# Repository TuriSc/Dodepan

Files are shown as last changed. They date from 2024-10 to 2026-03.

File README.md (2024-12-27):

# Dodepan ­— Digital Synth and Midi controller

This repository contains the firmware and construction files for Dodepan, a portable electronic musical instrument and Midi controller that features a built-in synthesizer, looper, and expressive modulation.

## Overview

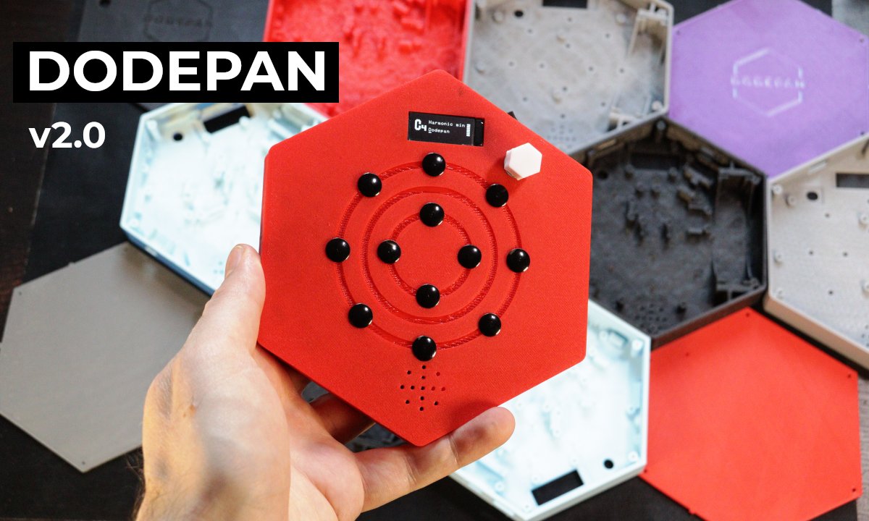
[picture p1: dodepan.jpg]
YouTube Video (https://youtu.be/9P0qgh-Bno8 "Dodepan")

[Video link](https://youtu.be/9P0qgh-Bno8)

Dodepan is played by tapping on its twelve (_dodeka_ in Greek) capacitive metal pads. The instrument features I²S audio output, a rotary encoder for parameter selection, an SSD1306 OLED display, and an MPU-6050 IMU for velocity and pitch bending data.

## What's New

Compared to the original version, this iteration offers several improvements:

* Raspberry Pi Pico 2 as the central unit
* Better audio quality using an I²S DAC and power amplifier
* An SSD1306 OLED display
* A rotary encoder for navigation and parameter selection
* Direct digital synthesis engine
* 9 instrument presets, plus 4 slots for user presets
* Filter cutoff frequency modulation controlled by device tilt
* Sequence looper with diatonic transport selector
* Volume control
* Extended note range
* Automatic storage and retrieval of last used settings
* Fewer components

Dodepan v2 also sports an amplified output with speaker disable. While it can work fine with some headphones, the signal from the audio jack must be attenuated before being connected to sensitive equipment. A resistor between 1.2KΩ and 4.7KΩ is recommended.

## Synth engine and Instrument Parameters

The synth Dodepan is based on is [PRA32-U](https://github.com/risgk/digital-synth-pra32-u) by Ryo Ishigaki.
The instrument parameters section allows you to change the 46 parameters of the synthesizer. Press the encoder button to switch between parameter selection and value editing, and rotate the knob to change parameter or value. Long-press the encoder button to exit this section and store the current instrument to one of the four user presets.

## Looper

The looper section records note on/off events. To enable it, select the looper screen and press the encoder button. An empty square icon indicates no recording. Start playing a melody to automatically start recording. Press the encoder button to stop the recording and start playback. You can play on top of the looper. Press the button again to pause or restart playback. Rotate the encoder knob to perform diatonic transport of the recording.

## IMU Configuration

To make the instrument more expressive, an MPU-6050 IMU (Inertial Measurement Unit) is used to convert the intensity of a tap into velocity data, so that hard taps play louder and soft taps play quieter. The IMU also provides gyroscope data, which Dodepan uses to perform pitch bending, like in a previous toy synth I made, [TS-DET1](https://github.com/TuriSc/TS-DET1).

From the IMU config screen, you can enable or disable pitch bending and filter cutoff modulation when the Dodepan is tilted on the X and Y axes.

## Automatic Save

Dodepan automatically stores the current settings into its memory, with a configurable delay (default 10 seconds) to minimize flash wear. Stored settings are loaded automatically at startup.
The Pico onboard LED will flash briefly when data is being written to its flash memory.

## Built-in Scales

Sixteen built-in scales or modes are available:

* Major (ionian)
* Natural minor (aeolian)
* Harmonic minor
* Dorian
* Lydian
* Mixolydian
* Locrian
* Phrygian
* Phrygian dominant
* Pentatonic major (Diatonic)
* Pentatonic minor
* Pentatonic blues
* Arabian
* Oriental
* Japanese
* Chromatic

You can add up to four custom scales from the scale editing screen, which is accessed by long-pressing the rotary encoder switch while the current scale is selected.

## Secondary menu screens
A number of settings and features are accessible from secondary onboard menu screens.

| Selection  | On press | On long press |
|---|---|---|
| Key | Enter key selection mode | Display about screen |
| Scale | Enter scale selection mode | Enter scale edit screen (long press to exit) |
| Instrument | Enter instrument selection mode | Enter instrument edit screen (long press to exit)  |
| Volume | Enter volume level selection mode | Enter display contrast selection screen |
| Looper | Activate, play/pause | Exit looper screen |
| IMU config | Enter IMU config mode | Exit IMU config screen |

## Installation

To install the firmware, simply flash the provided uf2 file that matches your microcontroller (RP2040 for Raspberry Pi Pico and RP2350 for Raspberry Pi Pico 2). If you want to change any configuration options, you'll need to build the sources and generate your own uf2 file.

## Configuration

All user-configurable options are in the file [config.h](config.h). You can, for example, change pin numbers, MPR121 sensitivity, and timing-related values.

## Compiling

Building the sources requires the Raspberry Pi Pico SDK.

```
git clone https://github.com/TuriSc/Dodepan/
cd Dodepan
git submodule update --init --recursive
mkdir build && cd build
cmake -DPICO_PLATFORM=rp2350 ..
make
```

If you are compiling for RP2040, omit the PICO_PLATFORM directive:
```
cmake ..
make
```
A Raspberry Pi Pico (RP2040) will work but with some limitations. Polyphonic instruments might crackle a bit. To mitigate this, set the Voice Mode parameter to 2 (monophonic).

## Bill of Materials

* Raspberry Pi Pico 2 (RP2350)
* MPR121 (touch sensor)
* GY-521 IMU (MPU-6050 breakout board)
* MAX98357 I²S DAC
* 100KΩ resistor
* 2x 2.2KΩ resistors (external I²C pullup resistors)
* 1000uF electrolytic capacitor (for decoupling, optional. A smaller value is fine)
* Rocker switch (12mm x 8mm hole size)
* 18650 Lithium battery
* One pair of springs for 18650 battery
* TP4056 (charger module)
* SSD1306 0.91" OLED display
* EC11 rotary encoder (12mm height recommended)
* Speaker (4Ω 3W recommended, but 8Ω 2W is fine too)
* 3.5mm audio jack (switched)
* Metal pushpins (to use as touch pads)
* Electrical wire (multi strand 26 AWG)
* M2x5mm screws (10x for the PCB version, 22x for handwired build)
* 3D-printed enclosure, lid, and encoder knob. Handwired build also needs a few small parts

## Schematic

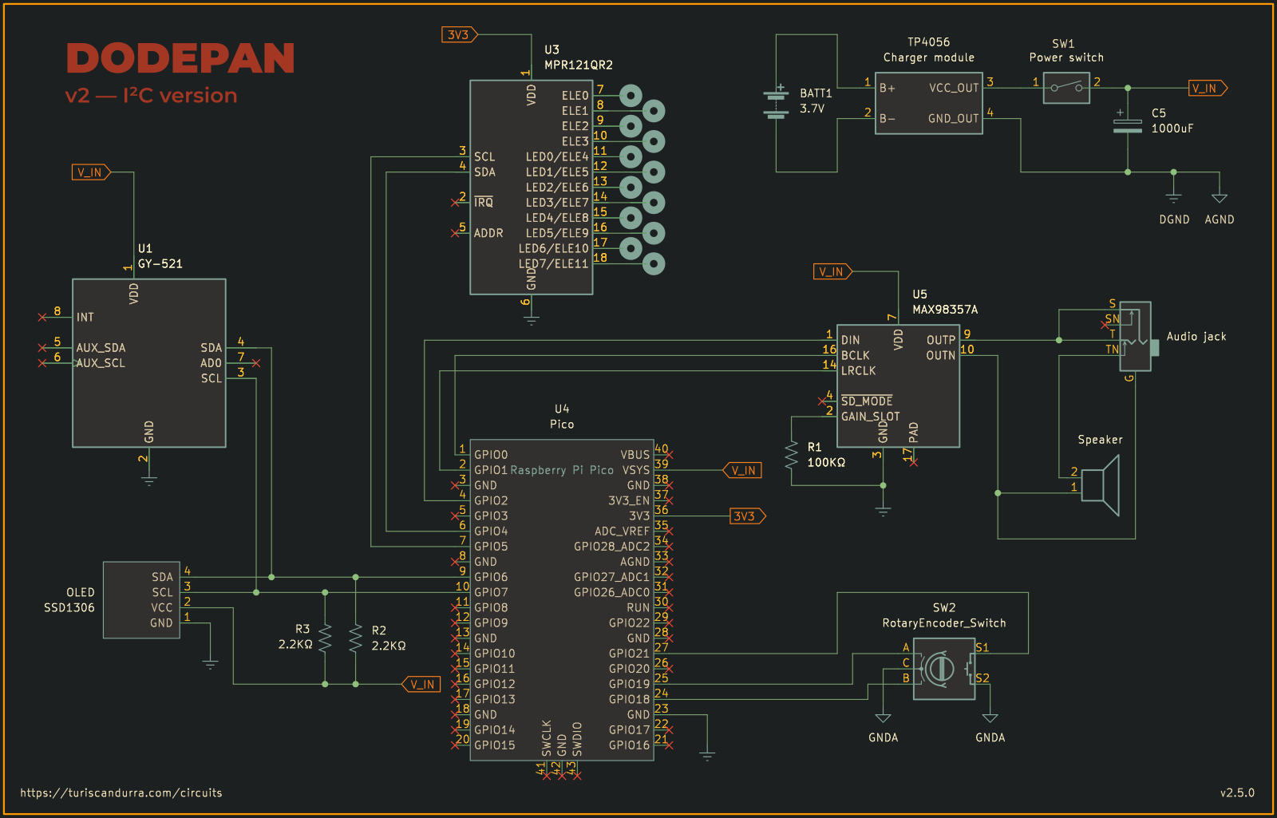
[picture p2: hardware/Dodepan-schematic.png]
Dodepan schematic


[PDF version](hardware/Dodepan-schematic.pdf)

## Step-by-step assembly guide (PCB version)

See [hardware/assembly guide/README.md](hardware/assembly guide/README.md)

## Known bugs

- Playing multiple notes simultaneously while also turning the encoder knob can result in the OLED display glitching.

## More Information

Dodepan is an original project.
Δώδεκα (dodeka) means twelve in Greek. Pan is a reference to the handpan, the instrument that inspired the first version of Dodepan.
The source code for the first version can be found on the version_1 branch at [TuriSc/Dodepan](https://github.com/TuriSc/Dodepan/tree/version_1).  
Similar projects can be found on my blog: [turiscandurra.com/circuits](https://turiscandurra.com/circuits/)

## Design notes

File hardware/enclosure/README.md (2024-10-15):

## Dodepan enclosure 3D models

This folder contains the STL and OpenScad files for the enclosure of Dodepan.

### PCB version

You only need to print:
- Enclosure_PCB
- Lid
- Encoder knob

### Handwired version

You might have to create two or more standoffs to support your speaker.
You also need to print:
- 2x OLED bracket
- 3x Standoff peg (or more if you need them for your speaker)

### Optional print settings

- Fill pattern: Honeycomb
- Fill angle: 30
- Bridging angle: 180

With some filaments the knob might have to be printed at 101% or 99% of its original size due to the filament's tendency to shrink or expand during the printing process.

I printed my lid upside down, to give it a smooth finish and a nice effect on the hexagons. Remember to set the bridging angle to a specified value.

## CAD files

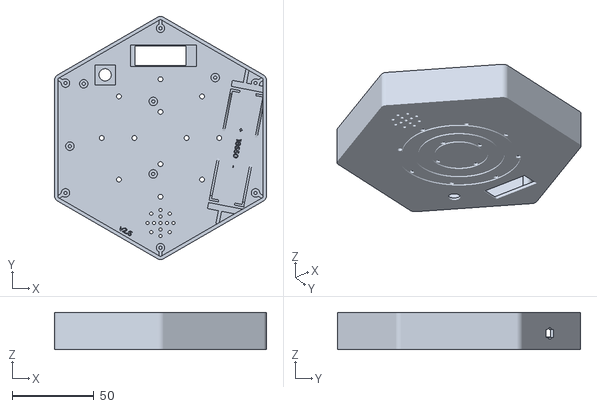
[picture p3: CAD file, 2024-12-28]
hardware/enclosure/Enclosure_PCB.stl
129.9 x 148.8 x 22.9

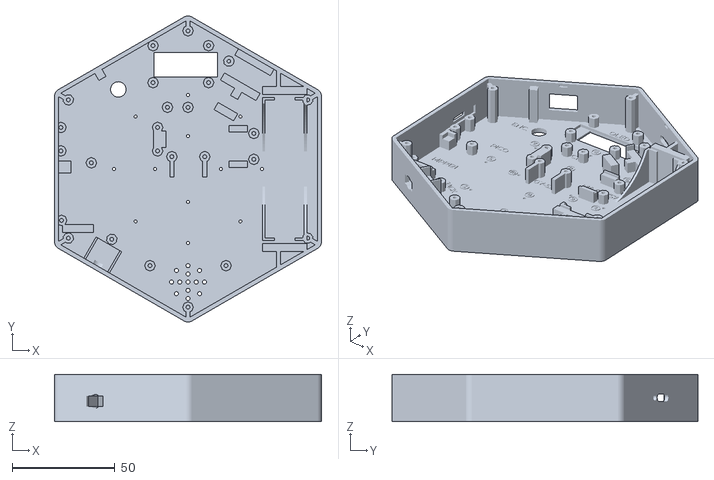
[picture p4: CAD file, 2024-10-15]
hardware/enclosure/Enclosure_handwired.stl
129.9 x 148.8 x 22.9

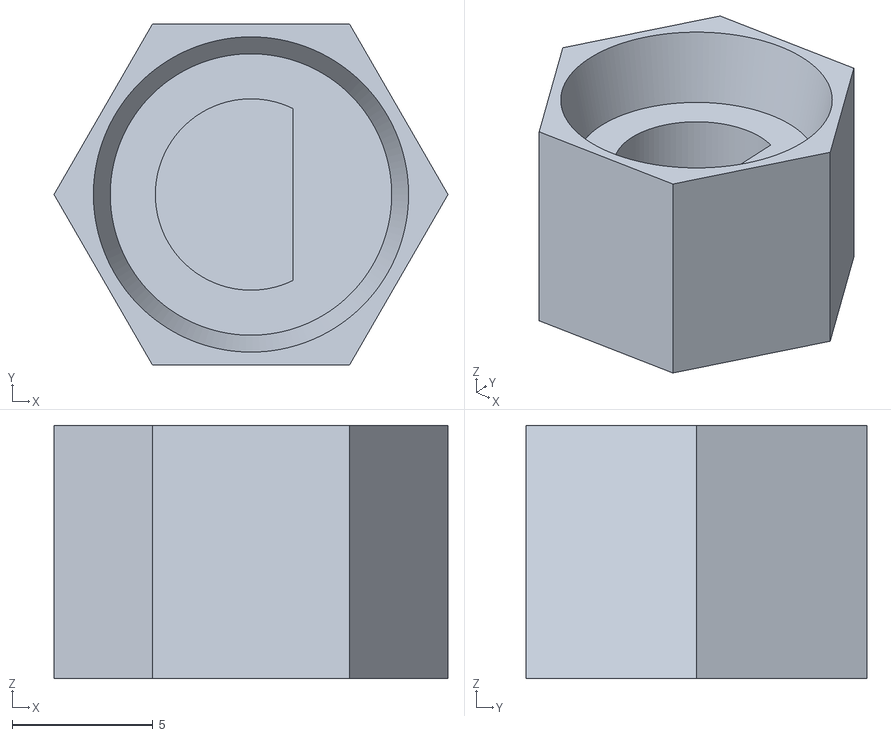
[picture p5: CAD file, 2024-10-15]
hardware/enclosure/Encoder knob.stl
14.0 x 12.1 x 9.00

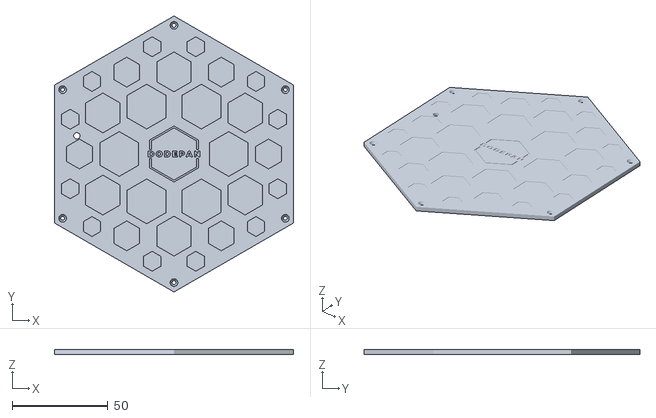
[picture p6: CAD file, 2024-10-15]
hardware/enclosure/Lid.stl
124.9 x 144.2 x 2.40

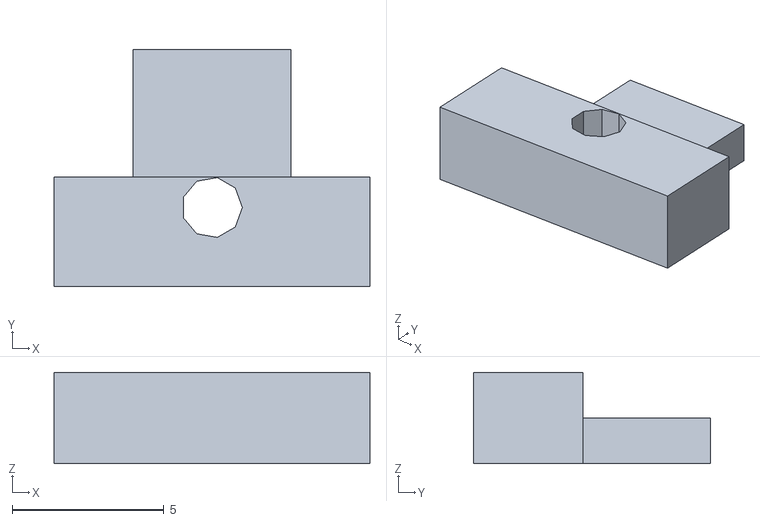
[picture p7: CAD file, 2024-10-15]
hardware/enclosure/Standoff peg.stl
10.4 x 7.80 x 3.00

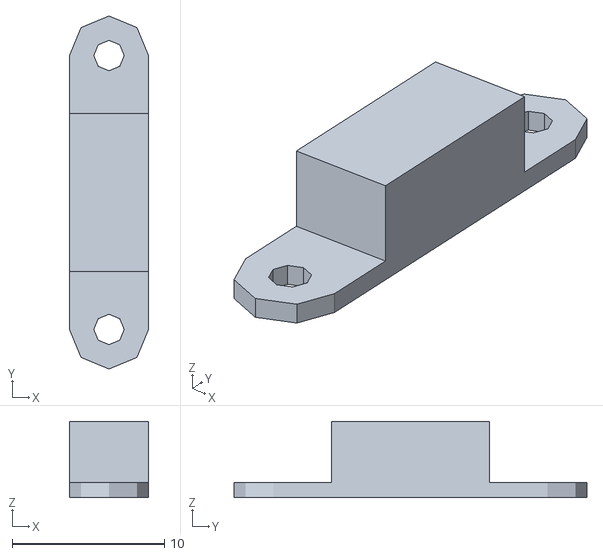
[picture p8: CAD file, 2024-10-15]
hardware/enclosure/OLED bracket.stl
5.20 x 23.2 x 5.00

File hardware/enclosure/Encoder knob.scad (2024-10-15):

// File: Encoder knob.scad
// Description: Knob for an EC11 rotary encoder with a 6mm D-shaft
// Author: Turi Scandurra
// Website: https://www.turiscandurra.com/circuits
// Date: 2024-09-20
// License: MIT License

roof_height = 1;
tolerance = 0.4;
shaft_r = 3 + tolerance;

module knob(height, inset, radius, sides) {
    difference() {
        cylinder(r=radius,h=height,$fn=sides);
        difference() {
            cylinder(r=shaft_r,h=height-roof_height,$fa=0.01,$fs=0.25);
            translate([1.5,-4,0])
                cube([4,8,height-2]);
        }
        cylinder(r1=5.6,r2=5.0,h=inset,$fa=0.01,$fs=0.25);
    }
}

translate([0,0,8])
    rotate([180,0,0])
        knob(9, 3, 7, 6);

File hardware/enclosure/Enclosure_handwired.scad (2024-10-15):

// File: Enclosure_handwired.scad
// Description: Enclosure for Dodepan, handwired (no PCB) version
// Author: Turi Scandurra
// Website: https://www.turiscandurra.com/circuits
// Date: 2024-08-26
// License: MIT License

version_label = "v1.7";

enclosure_r = 75;
inner_h = 20.5;
tolerance = 1.0;

wall_w = 2.4;
floor_h = 2.4;
mount_w = 1.6;
mount_r = enclosure_r - 3.8;

electrode_hole_r = 0.75;
speaker_hole_r = 1.0;
screw_r = 1.0;

electrodes_r_maj = 36;
electrodes_r_min = 16;

snapfit_depth = 2;

pico_mount_height = 9 - floor_h;

six_angles=[0, 60, 120, 180, 240, 300];

// Computed values
enclosure_h = inner_h + floor_h;
enclosure_side_r = enclosure_r * 0.866;

function center(x,y,z) = [x/-2,y/-2,z/-2];

module lid_mount() {
    rotate(-90) translate([-1,-2,0]) cube([2,4,inner_h]);
    translate([-4,0,0]) standoff(inner_h);
}
  
module face_circles() {
    depth = 1;
    rotate_extrude($fn=128) {
        for (radius=[electrodes_r_min, (electrodes_r_min+electrodes_r_maj)/2, electrodes_r_maj]) {
            translate([radius, 0, 0]) square([electrode_hole_r*2,electrode_hole_r*depth], center=true);
        }
    }
}

module rounded_corners() {
    for (a=six_angles) {
            rotate([0,0,a]) translate([enclosure_r-4-0.600, 0, 0]) rotate([0,0,-30]) rotate_extrude(angle=60, $fn=64) {
            translate([4, 0, 0]) square([4,enclosure_h]);
        }
    }
}

module casing() {
    difference() {
        cylinder(r=enclosure_r, h=enclosure_h, $fn=6);
        translate ([0, 0, floor_h]) cylinder(r=(enclosure_r-wall_w), h=enclosure_h, $fn=6);
        rounded_corners();
    }
}

module lid_mounts() {
    for (angle=six_angles) {
        rotate([0,0,angle]){
            translate([mount_r,0,0]) lid_mount();
        }
    }
}

module snapfit_casings() {
    for (angle=[60, 120]) {
        rotate([0,0,30+angle]){
            translate([enclosure_side_r-snapfit_depth,0,inner_h+1]) cube([2,4,1.2], center=true);
        }
    }
}

module electrode_holes() {
        for ( i = [0 : 7] ){
            rotate([0,0,(45*i)])
            translate([0,electrodes_r_maj,0])
            cylinder(h=floor_h, r=electrode_hole_r, $fn=24);
        }
        for ( i = [0 : 3] ){
            rotate([0,0,(90*i)])
            translate([0,electrodes_r_min,0])
            cylinder(h=floor_h, r=electrode_hole_r, $fn=24);
        }
}

module speaker_holes() {
        cylinder(h=floor_h, r=speaker_hole_r, $fn=24);
        for ( i = [0 : 7] ){
            rotate([0,0,(45*i)])
            translate([0,8,0])
            cylinder(h=floor_h, r=speaker_hole_r, $fn=24);
        }
        for ( i = [0 : 3] ){
            rotate([0,0,(90*i)])
            translate([0,4,0])
            cylinder(h=floor_h, r=speaker_hole_r, $fn=24);
        }
}

module battery_holder() {
    max_object_height=inner_h-floor_h;
    translate([0,-13,0]) rotate(180) label("+    18650    -");
    difference() {
        union() {
            // Main shape
            translate(center(69+11,18+3.6,0)) cube([69+11,18+3.6,max_object_height]);
            // Supports
            translate(center(96,-4,0)) cube([96,2,max_object_height]);
        }
        // Battery socket
        translate(center(65+2,18+1,0)) cube([65+2,18+1,max_object_height]);
        // Positive terminal socket
        translate([35.5,0,0]) translate(center(1.5,24,0)) cube([1.5,24,max_object_height]);
        // Negative terminal socket
        translate([-35.5,0,0]) translate(center(1.5,24,0)) cube([1.5,24,max_object_height]);
        // Terminal openings
        translate(center(70,10,0)) cube([70,10,max_object_height]);
        // Circular cut
        translate([0,20,35]) rotate([90,0,0]) cylinder(h=55, r=36, $fn=128);
    }
}

module standoff(height) {
    difference() {
        cylinder(r = mount_w + screw_r, h = height,$fn=8);
        cylinder(r = screw_r, h = height,$fn=8);
    }
}
module label(string) {
    linear_extrude(height = 0.5)
    text(string, font = "Montserrat", halign="center", valign="center", size=3);
}

module GY_521() {
    translate([0,3,0]) label("GY-521");
    translate([8.15,9,0]) standoff(8);
    translate([7.15,-1,0]) cube([2,8,8]);
    translate([-7.85,9,0]) standoff(8);
    translate([-8.85,-1,0]) cube([2,8,8]);
}

module pico() {
    label("PICO");
    translate([-22.8,0,0]) {  // Top holes
        translate([0,-5.7,0]) standoff(pico_mount_height);
        translate([0,5.7,0]) standoff(pico_mount_height);
    }
    translate([24.2,0,0]) { // Bottom holes
        translate([0,-5.7,0]) standoff(pico_mount_height);
        translate([0,5.7,0]) standoff(pico_mount_height);
        translate([-2,-4,0]) cube([6,8,pico_mount_height]);
        translate([2,-4,0]) cube([2,8,pico_mount_height+1]);
    }   
}

module TP4056() {
    translate([0,-13,0]) label("TP4056");
    difference() {
        translate([-10,-8,0]) cube([20,4,8]);
        translate([-10,-8,5.4]) cube([19,4,8]);
    }
    difference() {
        translate([-10,-22,0]) cube([20,4,8]);
        translate([-9,-22,5.4]) cube([18,4,8]);
    }
    translate([-5.5,-36,0]) cube([11,4,8]);
    translate([-2,-26,0]) cube([4,4,5.4]);
    translate([-11,-12,0]) difference() {
        cylinder(r = mount_w + screw_r, h = 5.4);
        cylinder(r = screw_r, h = 5.4);
    }
}

module TP4056_holes() {
    rotate([90,0,0])
    linear_extrude(5) {
        hull() {
            translate([-3.6,0,0]) circle(1.8, $fn=64);
            translate([3.6,0,0]) circle(1.8, $fn=64);
        }
        translate([7.6,0,0]) circle(1.4, $fn=64); // LED hole
    }
}

module electrode_label(string) {
    linear_extrude(height = 0.5){
        text(string, font = "Montserrat", halign="center",valign="center",size=2.2);
        difference() {
            circle(2.4, $fn=16);
            circle(2, $fn=16);
        }
    }
}

module electrode_labels() {
    translate([0, -12]) electrode_label("0");
    translate([0, -32]) electrode_label("1");
    translate([28, -23]) electrode_label("2");
    translate([-29.5, -25]) electrode_label("3");
    translate([33, -2.5]) electrode_label("4");
    translate([-36, 4]) electrode_label("5");
    translate([28.3, 28.3]) electrode_label("6");
    translate([-28.3, 28.3]) electrode_label("7");
    translate([0, 40]) electrode_label("8");
    translate([19, -2.5]) electrode_label("9");
    translate([-19.5, 0]) electrode_label("10");
    translate([0, 20]) electrode_label("11");
}

module MAX98357() {
    amp_mount_h = 5;
    label("MAX98357");
    rotate([0,0,-90]) {
        translate([-6.3,7]) standoff(amp_mount_h);
        translate([-9.2,-5,0]) cube([2.2,9,amp_mount_h]);
        translate([-10.2,-5,0]) cube([1,9,amp_mount_h+1]);
        mirror([180,0,0]){
            translate([-6.3,7]) standoff(amp_mount_h);
            translate([-9.2,-5,0]) cube([2.2,9,amp_mount_h]);
            translate([-10.2,-5,0]) cube([1,9,amp_mount_h+1]);
        }
    }
}
    
module audio_socket() {
    audio_socket_mount_h = 5;
    translate([7,8,0]) label("JACK");
    translate([7,2.8,0]) standoff(audio_socket_mount_h);
    difference() {
        translate([-.2,-12,0]) cube([14.4,12,10]);
        translate([.8,-13,5]) cube([12.4,14.4,5]);
        translate([7.2,-10,7.5]) rotate([90,0,0]) cylinder(r=3.4,h=5,$fn=64);
    }
}

module audio_socket_hole() {
    translate([2.4,-20,5]) cube([9.4,12.4,5]);
    translate([7.2,-10,7.5]) rotate([90,0,0]) cylinder(r=3.4,h=5,$fn=64);
}

module speaker_mount() {
    speaker_mount_h=8;
    translate([0,-4]) label("SPEAKER");
    translate([-18.5,-9]) standoff(speaker_mount_h);
    translate([18.5,-9]) standoff(speaker_mount_h);
}

module OLED() {
    translate([-1.5,8]) label("OLED");
    oled_mount_top_h=5;
    translate([9,-9]) standoff(oled_mount_top_h);
    translate([9,9]) standoff(oled_mount_top_h);
    translate([-18,-9]) standoff(oled_mount_top_h);
    translate([-18,9]) standoff(oled_mount_top_h);
}

module MPR121() {
    rotate([0, 0, -90]) label("MPR121");
    mpr121_mount_h=5;
    translate([-16,-5,0]) cube([2,15,mpr121_mount_h]);
    translate([-18,-5,0]) cube([2,15,mpr121_mount_h+2]);
    difference() {
        translate([11,6,0]) cube([6,6,mpr121_mount_h+2]);
        translate([-15,-10,mpr121_mount_h]) cube([30,20,3]);
    }
    translate([-12,10.5]) standoff(mpr121_mount_h);
    translate([16,-4]) standoff(mpr121_mount_h);
}

module capacitor() {
    label("C1");
    cap_mount_h = 5;
    translate([-5,0,0]) standoff(cap_mount_h);
    translate([5,0,0]) standoff(cap_mount_h);
}
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

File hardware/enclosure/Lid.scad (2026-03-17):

// File: Enclosure_lid.scad
// Description: Enclosure lid for Dodepan
// Author: Turi Scandurra
// Website: https://www.turiscandurra.com/circuits
// Date: 2024-09-20
// License: MIT License

enclosure_r = 75;
tolerance = 1.0;
wall_w = 2.4;
height = 2.4;
mount_r = enclosure_r - 3.8;
enclosure_side_r = enclosure_r * 0.866;
inset_h = 0.6;
logo_w = 45;
logo_h = 48.8;
logo_inset = 0.6;
six_angles = [0, 60, 120, 180, 240, 300];

module graphics() {
    for (angle=six_angles) {
        // Ring 1
        rotate([0,0,angle])
                translate([22, 0, 0]) rotate([0,0,30]) cylinder(h=1, r=9, center=true, $fn=6);
        
        // Ring 2
        rotate([0,0,30+angle])
                translate([33, 0, 0]) cylinder(h=1, r=8, center=true, $fn=6);

        // Ring 3
        rotate([0,0,angle])
                translate([38, 0, 0]) rotate([0,0,30]) cylinder(h=1, r=6, center=true, $fn=6);
        
        // Ring 4 A
        rotate([0,0,18.5+angle])
                translate([44, 0, 0]) rotate([0,0,-48.5])cylinder(h=1, r=4, center=true, $fn=6);
            
        // Ring 4 B
        rotate([0,0,41.5+angle])
                translate([44, 0, 0]) rotate([0,0,-11.5])cylinder(h=1, r=4, center=true, $fn=6);
    }
}

module logo() {
    difference(){
        union(){
            polygon(points=[
                [-0.0, 26.89677],
                [2.36022, 26.89677],
                [3.13389, 26.82012],
                [3.81487, 26.59015],
                [4.37819, 26.21936],
                [4.79889, 25.72022],
                [5.06094, 25.10877],
                [5.14829, 24.40106],
                [5.06094, 23.69335],
                [4.79889, 23.0819],
                [4.37819, 22.58276],
                [3.81487, 22.21197],
                [3.13389, 21.982],
                [2.36022, 21.90535],
                [-0.0, 21.90535]
            ]);
            polygon(points=[
                [9.59164, 21.80552],
                [8.83936, 21.88931],
                [8.16552, 22.14066],
                [7.60398, 22.53997],
                [7.17437, 23.06764],
                [6.90697, 23.69691],
                [6.81784, 24.40106],
                [6.90697, 25.10521],
                [7.17437, 25.73448],
                [7.60398, 26.26215],
                [8.16552, 26.66146],
                [8.83936, 26.91281],
                [9.59164, 26.9966],
                [10.34214, 26.91281],
                [11.01063, 26.66146],
                [11.57573, 26.26215],
                [12.00178, 25.73448],
                [12.27453, 25.10521],
                [12.36544, 24.40106],
                [12.27453, 23.69691],
                [12.00178, 23.06764],
                [11.57573, 22.53997],
                [11.01063, 22.14066],
                [10.34214, 21.88931]
            ]);
            polygon(points=[
                [14.2917, 26.89677],
                [16.65192, 26.89677],
                [17.42559, 26.82012],
                [18.10657, 26.59015],
                [18.66988, 26.21936],
                [19.09059, 25.72022],
                [19.35264, 25.10877],
                [19.43999, 24.40106],
                [19.35264, 23.69335],
                [19.09059, 23.0819],
                [18.66988, 22.58276],
                [18.10657, 22.21197],
                [17.42559, 21.982],
                [16.65192, 21.90535],
                [14.2917, 21.90535]
            ]);
            polygon(points=[
                [25.37363, 22.99633],
                [25.37363, 21.90535],
                [21.36624, 21.90535],
                [21.36624, 26.89677],
                [25.28093, 26.89677],
                [25.28093, 25.80579],
                [22.76384, 25.80579],
                [22.76384, 24.96438],
                [24.98145, 24.96438],
                [24.98145, 23.90905],
                [22.76384, 23.90905],
                [22.76384, 22.99633]
            ]);
            polygon(points=[
                [29.62446, 26.89677],
                [30.80101, 26.66859],
                [31.57112, 26.02684],
                [31.77434, 25.57583],
                [31.84208, 25.04995],
                [31.77434, 24.52407],
                [31.57112, 24.07306],
                [30.80101, 23.4313],
                [29.62446, 23.21025],
                [28.75453, 23.21025],
                [28.75453, 21.90535],
                [27.34267, 21.90535],
                [27.34267, 26.89677]
            ]);
            polygon(points=[
                [36.80596, 22.87511],
                [34.6953, 22.87511],
                [34.30312, 21.90535],
                [32.86274, 21.90535],
                [35.06609, 26.89677],
                [36.45656, 26.89677],
                [38.66705, 21.90535],
                [37.19815, 21.90535]
            ]);
            polygon(points=[
                [45.0, 26.89677],
                [45.0, 21.90535],
                [43.83771, 21.90535],
                [41.63436, 24.56507],
                [41.63436, 21.90535],
                [40.25102, 21.90535],
                [40.25102, 26.89677],
                [41.41331, 26.89677],
                [43.61666, 24.23706],
                [43.61666, 26.89677]
            ]);
            // Upper outline
            polygon(points=[
                [22.4999, 48.80217],
                [1.3681, 36.60185],
                [1.3681, 28.42472],
                [2.79564, 28.42472],
                [2.79564, 35.77715],
                [22.4999, 47.15299],
                [42.20416, 35.77715],
                [42.20416, 28.42472],
                [43.63193, 28.42472],
                [43.63193, 36.60185]
            ]);
            // Lower outline
            polygon(points=[
                [1.3681, 20.37743],
                [1.3681, 12.20031],
                [22.4999, -1e-05],
                [43.63193, 12.20031],
                [43.63193, 20.37743],
                [42.20416, 20.37743],
                [42.20416, 13.02478],
                [22.4999, 1.64917],
                [2.79564, 13.02478],
                [2.79564, 20.37743]
            ]);
        };
        union(){
            // D1 island
            polygon(points=[
                [2.30318, 23.03198],
                [2.88076, 23.1229],
                [3.32999, 23.39565],
                [3.62412, 23.82883],
                [3.72217, 24.40106],
                [3.62412, 24.97329],
                [3.32999, 25.40648],
                [2.88076, 25.67922],
                [2.30318, 25.77013],
                [1.41186, 25.77013],
                [1.41186, 23.03198]
            ]);
            // O island
            polygon(points=[
                [9.59164, 22.97494],
                [10.27618, 23.1532],
                [10.76106, 23.65235],
                [10.93932, 24.40106],
                [10.76106, 25.14264],
                [10.27618, 25.64891],
                [9.59164, 25.82718],
                [8.9071, 25.64891],
                [8.42222, 25.14264],
                [8.24396, 24.40106],
                [8.42222, 23.65235],
                [8.9071, 23.1532]
            ]);
            // D2 island
            polygon(points=[
                [16.59488, 23.03198],
                [17.17246, 23.1229],
                [17.62168, 23.39565],
                [17.91582, 23.82883],
                [18.01387, 24.40106],
                [17.91582, 24.97329],
                [17.62168, 25.40648],
                [17.17246, 25.67922],
                [16.59488, 25.77013],
                [15.70355, 25.77013],
                [15.70355, 23.03198]
            ]);
            // P island
            polygon(points=[
                [29.5389, 24.32263],
                [30.19492, 24.50802],
                [30.41597, 25.04995],
                [30.19492, 25.59187],
                [29.5389, 25.7844],
                [28.75454, 25.7844],
                [28.75454, 24.32263]
            ]);
            // A island
            polygon(points=[
                [36.39238, 23.91618],
                [35.75063, 25.51344],
                [35.10888, 23.91618]
            ]);
        }
    }
}

module lid(){
    rotate([0,0,-30])
    difference(){
        // Main shape
        cylinder(r=enclosure_r-wall_w-tolerance/2, h=height, $fn=6);
        // Graphics
        translate([0,0,height]) rotate([0,0,30]) scale([1.3,1.3,inset_h]) graphics();
        // Logo
        rotate([0,0,30]) scale([0.6,0.6,1])
        translate([logo_w/-2, logo_h/-2, height - logo_inset]){
            linear_extrude(height = 1)
                logo();
        }
        // Screw holes
        for (angle=six_angles) {
            rotate([0,0,angle])
                translate([mount_r-4,0,0]) 
                    cylinder(h=height, r1=1, r2=2, $fn=48);
        }
        // BOOTSEL
        rotate([0,0,30]) translate([-50.75, 9.5]) cylinder(h=height, r=1.66, $fn=64);
    }
}

// Render the part
lid();

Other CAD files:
hardware/enclosure/Enclosure_PCB.scad
hardware/enclosure/OLED bracket.scad
hardware/enclosure/Standoff peg.scad

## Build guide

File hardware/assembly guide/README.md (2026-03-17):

# Dodepan step-by-step assembly guide (PCB version)

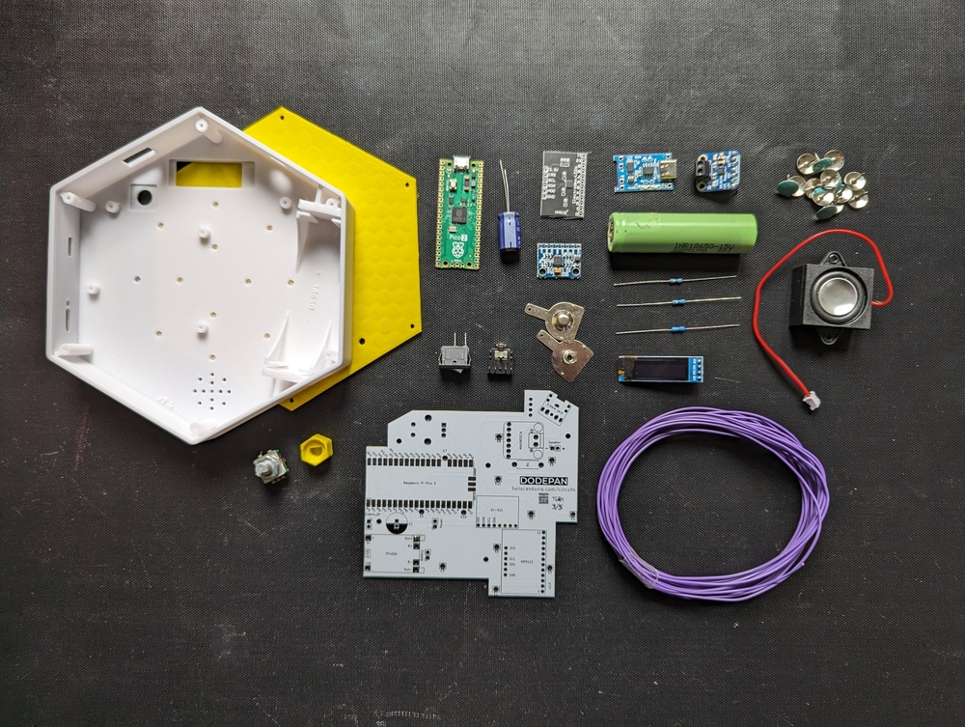
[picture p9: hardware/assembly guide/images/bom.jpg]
bom

1. Solder the MAX98357 module using its headers. Do not solder the speaker terminal to the module. Solder the two speaker output pins to the PCB
2. Solder the speaker terminal to the PCB
3. Solder the R1 resistor for MAX98357
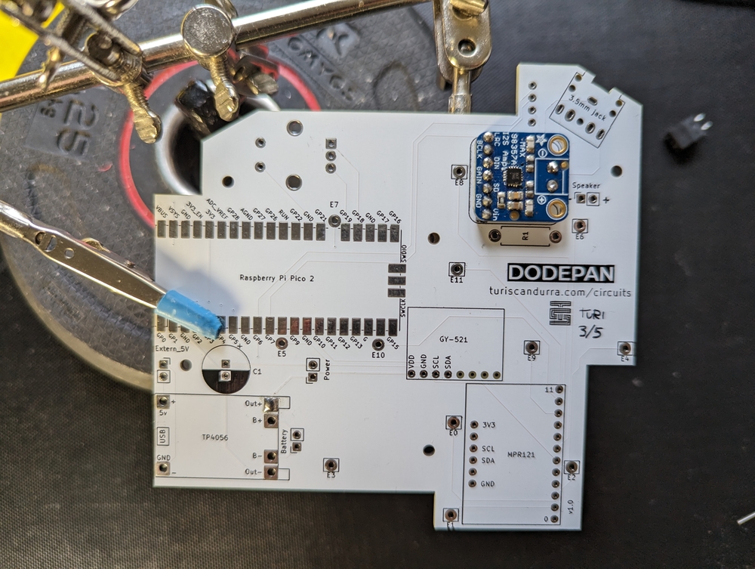
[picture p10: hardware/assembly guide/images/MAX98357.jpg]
MAX98357

1. Solder the GY-521 module to the PCB using its headers. Make sure it's perfectly aligned as it must be located at the center of movement of the enclosure
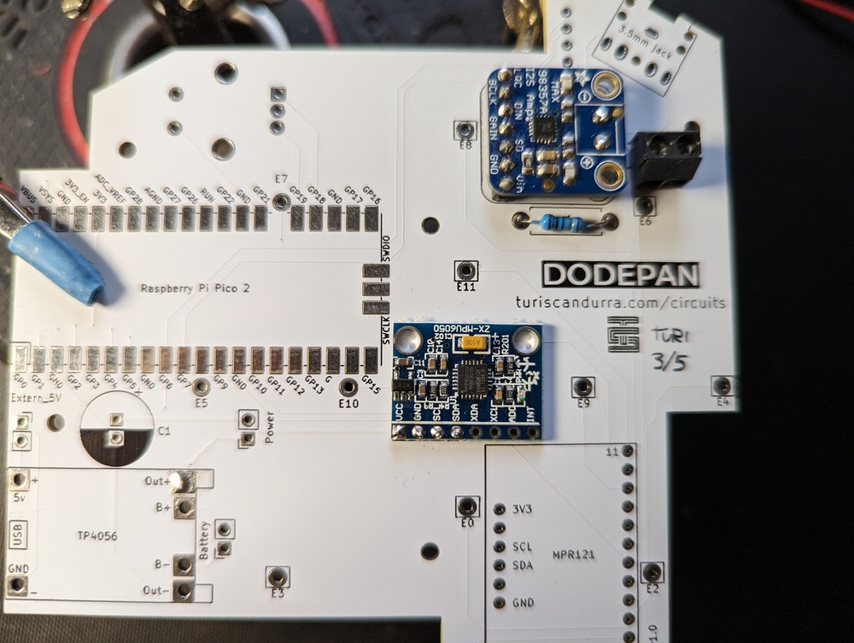
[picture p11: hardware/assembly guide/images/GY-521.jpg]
GY-521

1. Solder the external I²C pullup resistors R2 and R3. Please note that the old version of the PCB used in these pictures does not include the two resistors
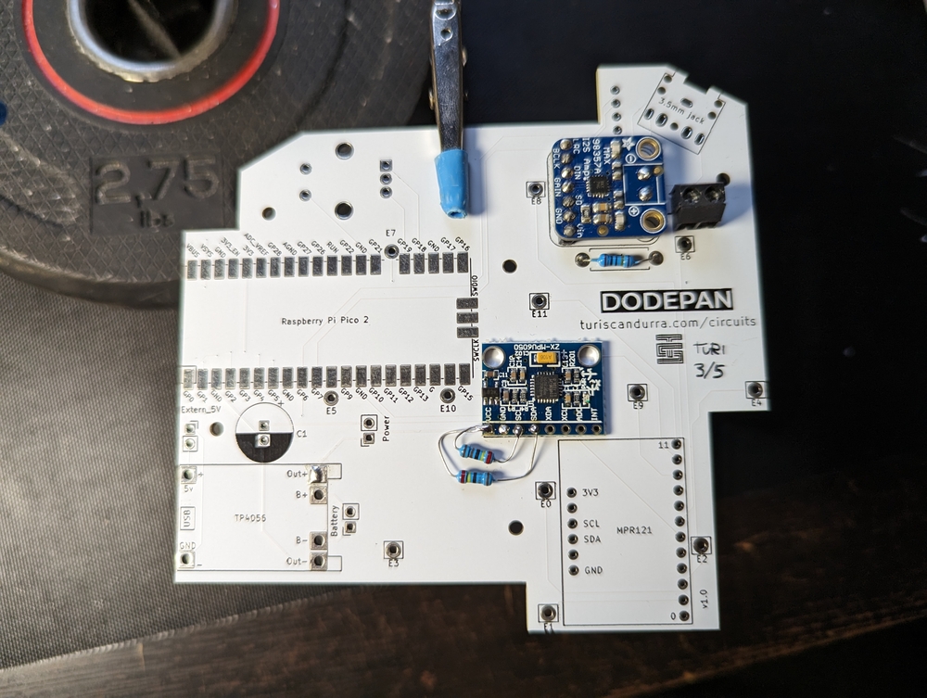
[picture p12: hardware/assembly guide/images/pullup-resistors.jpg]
pullup resistors

1. Solder the MPR121 module to the PCB using its headers
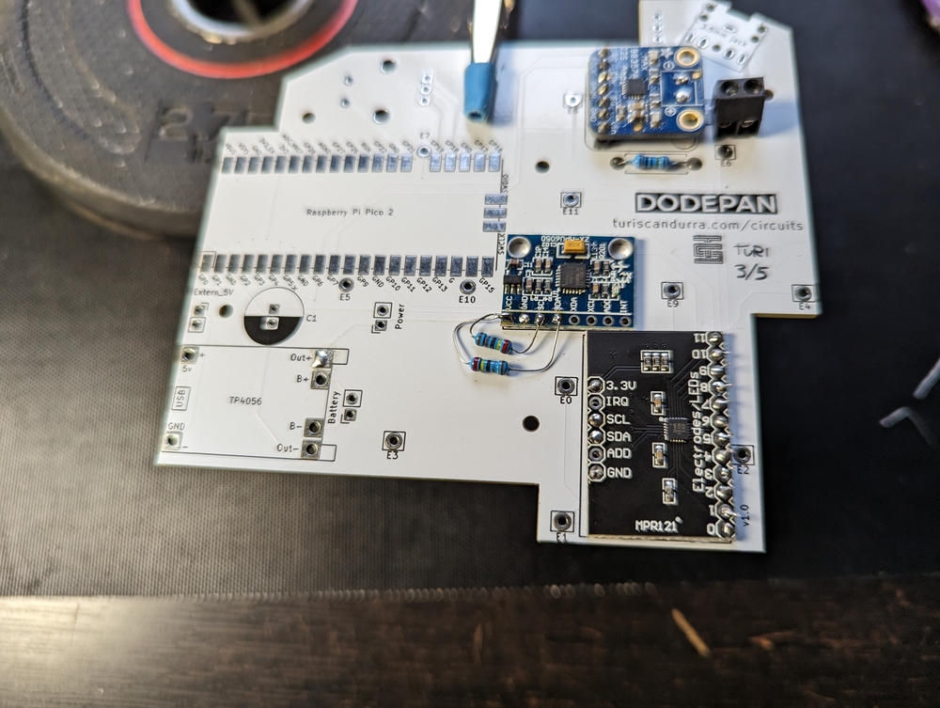
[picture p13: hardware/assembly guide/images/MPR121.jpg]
MPR121

1. Solder the jack socket
2. Solder the power switch wires so that they come out of the back side of the PCB. Do not solder them to the switch yet
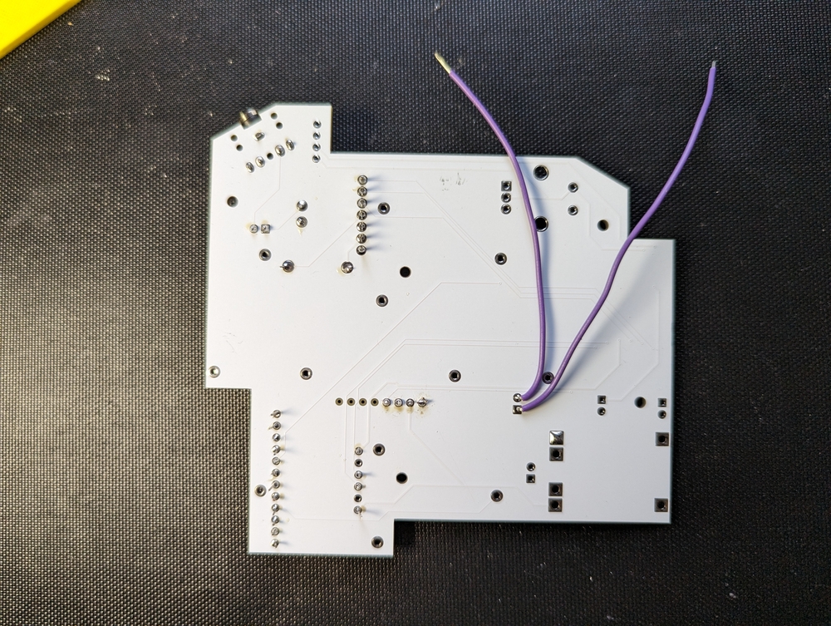
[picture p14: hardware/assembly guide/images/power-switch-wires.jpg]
power switch wires

1. Solder the battery wires so that they come out of the back side of the PCB
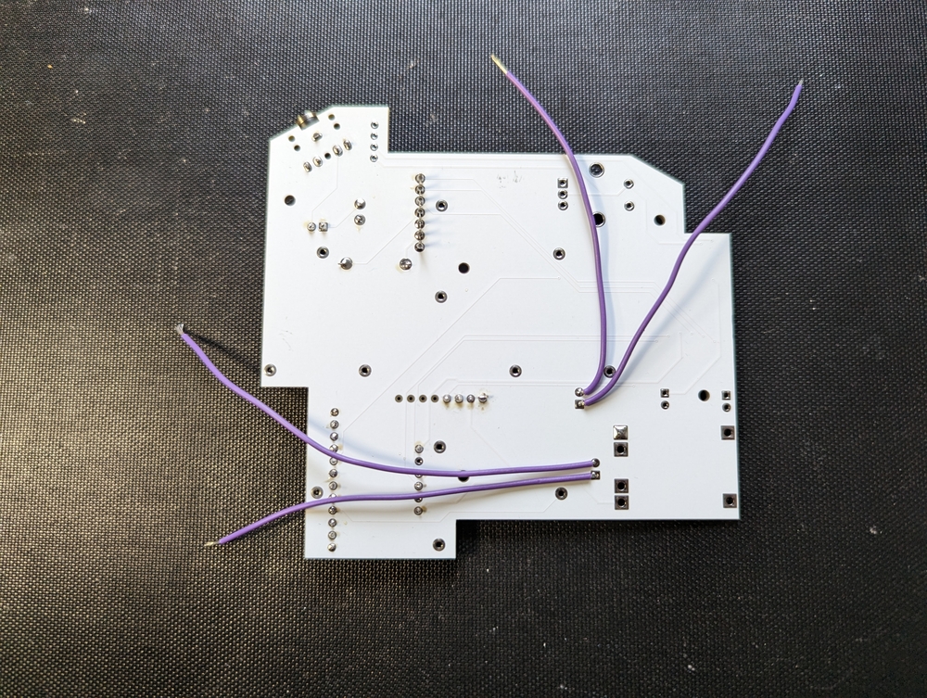
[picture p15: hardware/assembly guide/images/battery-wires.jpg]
battery wires

1. Solder six short solid core wires on the PCB to serve as "headers" for the TP4056 module. Avoid rigid header pins
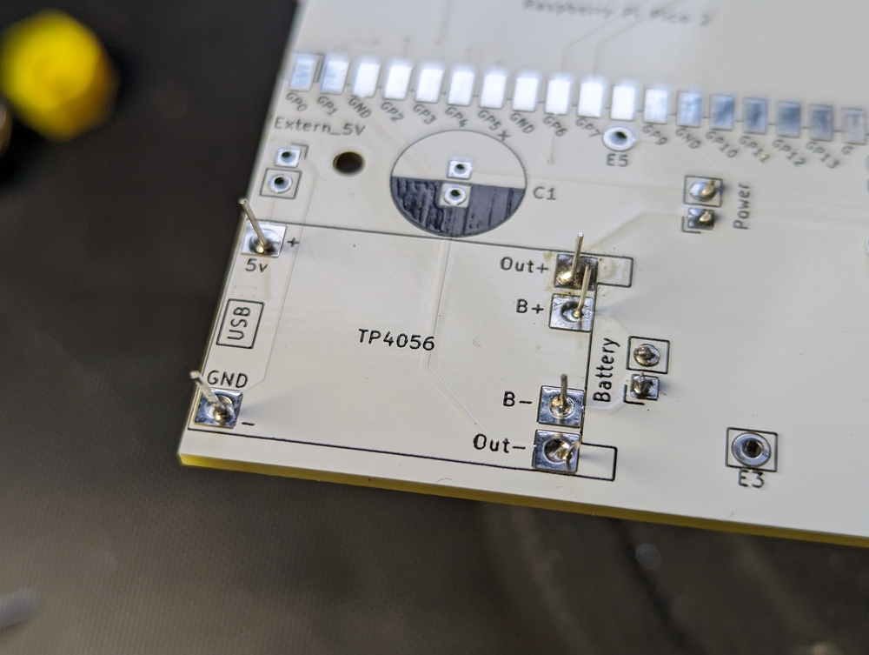
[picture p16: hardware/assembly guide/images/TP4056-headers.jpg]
TP4056 headers

1. Place a thin strip of insulating tape through the four back headers you just soldered (B+, B-, Out+, Out-) and over the four pads underneath. This is needed because there are slightly different TP4056 modules on the market and the pads might not perfectly align. Do not solder the TP4056 yet
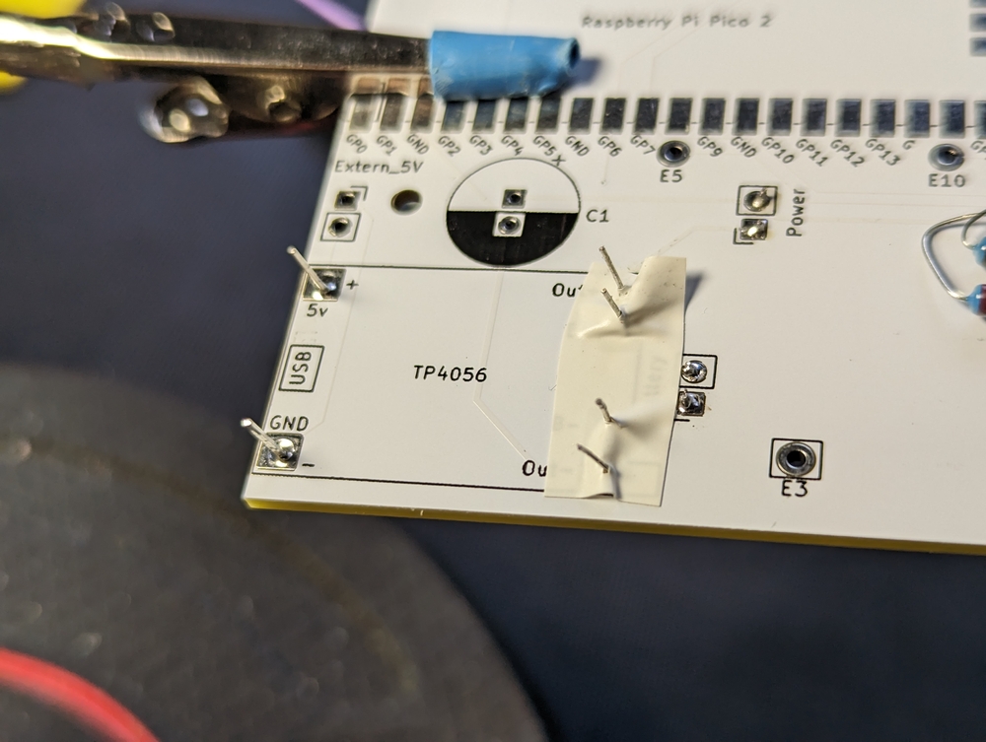
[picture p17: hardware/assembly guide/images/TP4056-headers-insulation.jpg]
TP4056 headers insulation

1. Solder the decoupling capacitor
2. Trim the short side of the OLED headers so they're almost flush with their board. Place the OLED into its slot on the enclosure
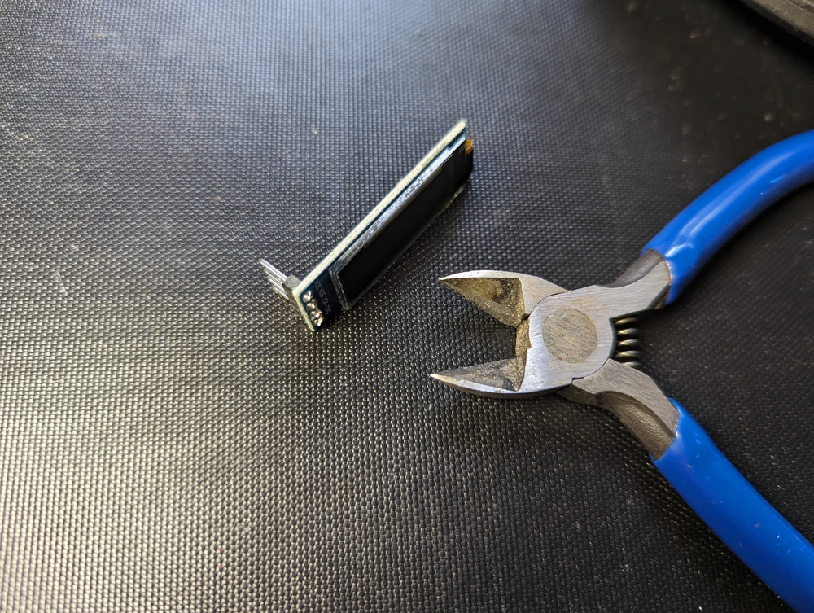
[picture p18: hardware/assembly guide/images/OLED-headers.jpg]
OLED headers

1. Place the rotary encoder on the back side of the PCB without soldering it. Remember to remove the washer and nut
2. Place the speaker inside the enclosure
3. Place the PCB in the enclosure, audio jack first, ensuring the rotary encoder and the OLED are in their correct position and the wires for the battery, the power switch, and the speaker are accessible. Bend the enclosure, not the PCB
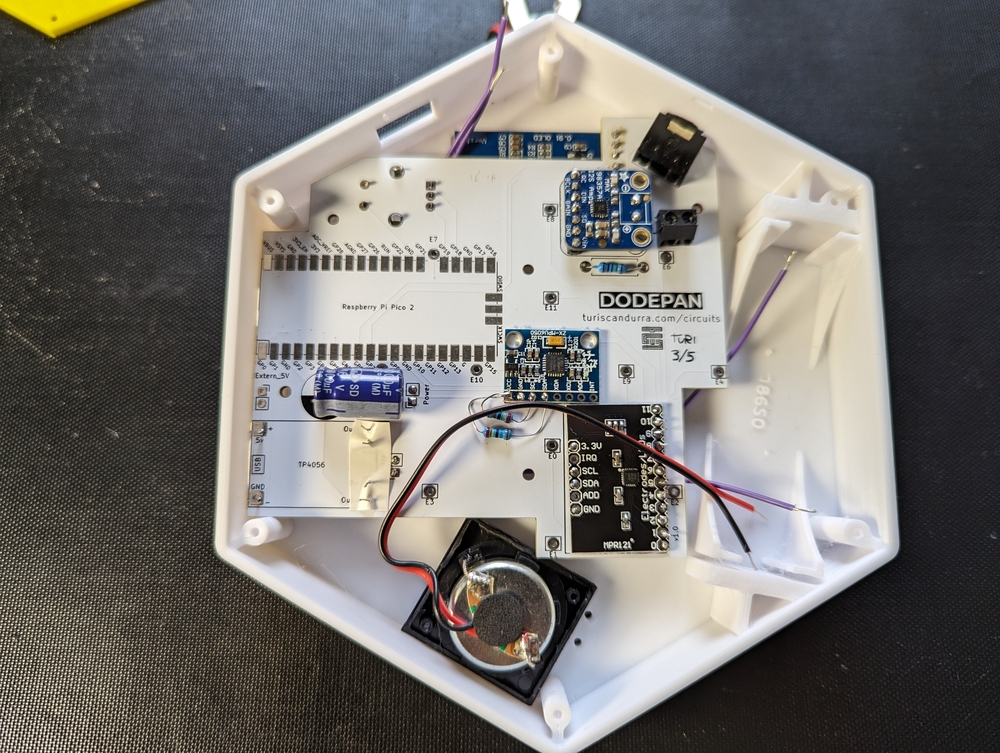
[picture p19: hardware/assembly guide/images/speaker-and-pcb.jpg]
speaker and pcb

1. Solder the OLED display to the PCB
2. Solder the rotary encoder to the PCB
3. Make sure the USB socket of the TP4056 module is fitting into its hole and solder the module to the PCB
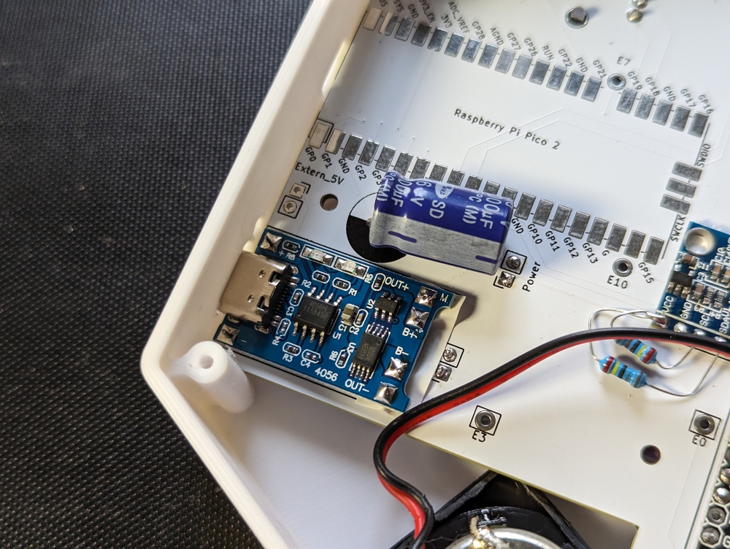
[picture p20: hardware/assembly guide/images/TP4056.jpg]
TP4056

1. Secure the PCB to the enclosure with the M2 screws
2. Place the power switch into its hole and solder its two wires to it
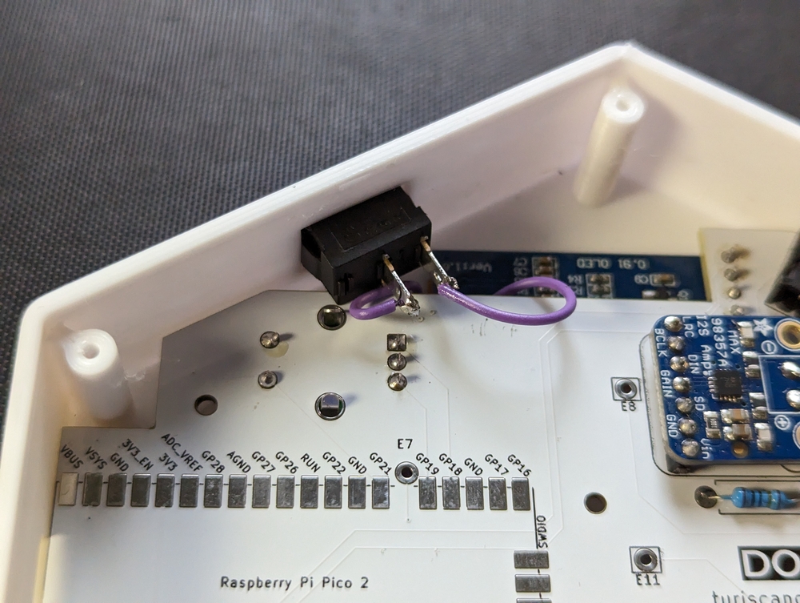
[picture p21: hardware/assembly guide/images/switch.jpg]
switch

1. Place the battery springs into their sockets, bend their tabs outward, and solder them to their wires
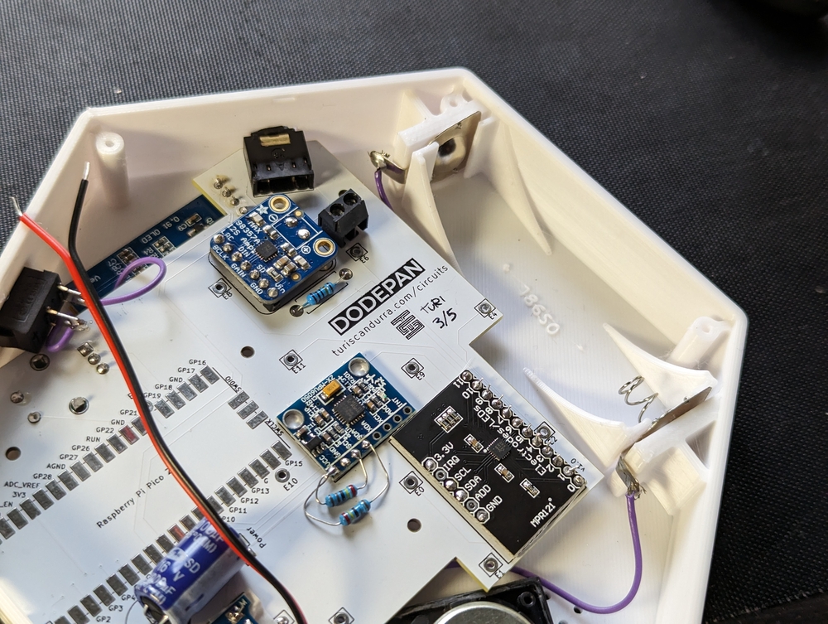
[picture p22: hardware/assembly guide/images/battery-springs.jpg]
battery springs

1. Place the Pico so that the Micro-USB socket goes fully through the enclosure wall. Align it with the pads on the PCB and use some tape to secure it in position as you solder it
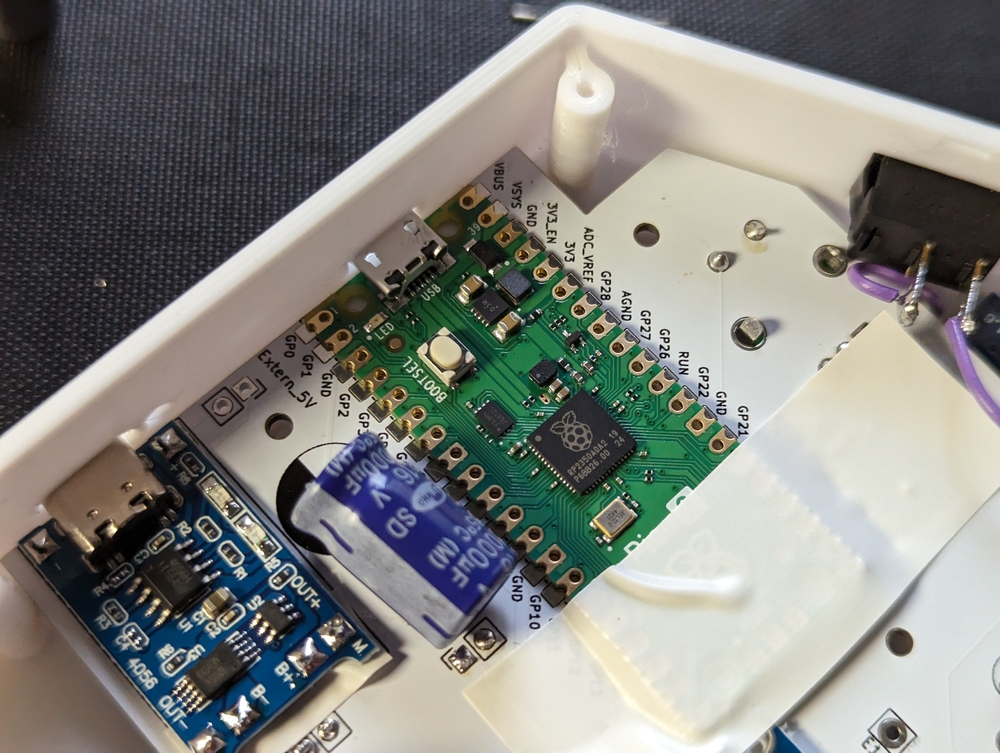
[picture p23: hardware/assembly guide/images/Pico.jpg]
Pico

1. Solder the twelve drawing pins/electrodes. If you painted the pins, be very quick as heat softens the enamel
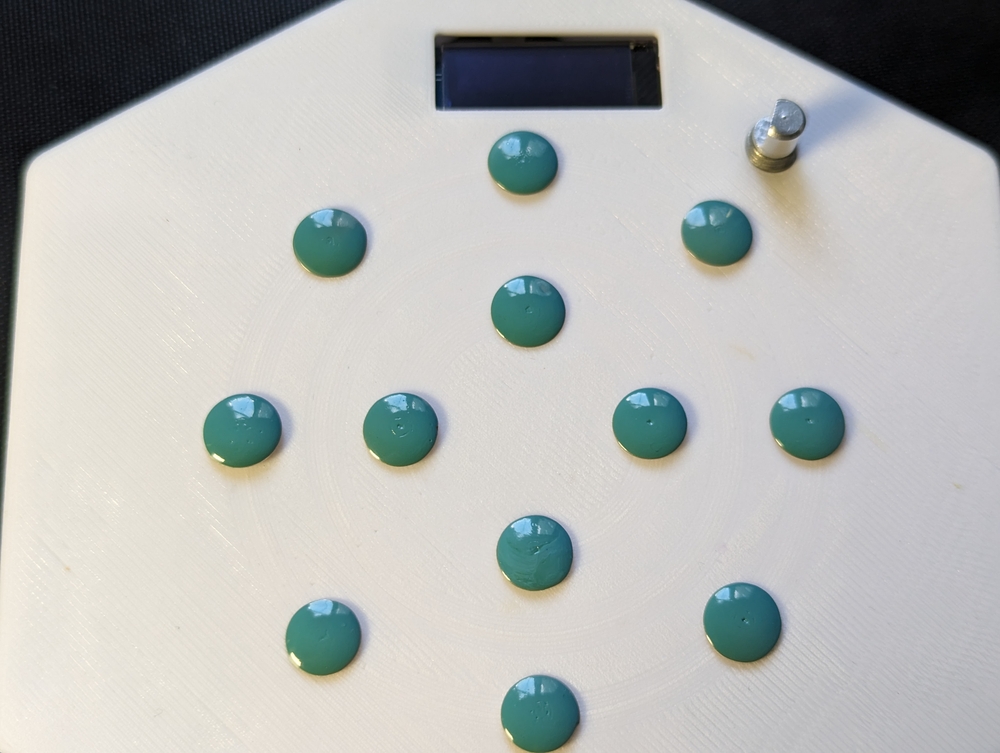
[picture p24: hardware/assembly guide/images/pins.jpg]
pins

1. Lock the speaker wires into the audio output terminal. Use some hot glue to secure the speaker in place 
2. Install the washer, nut, and knob on the rotary encoder
3. Install the battery
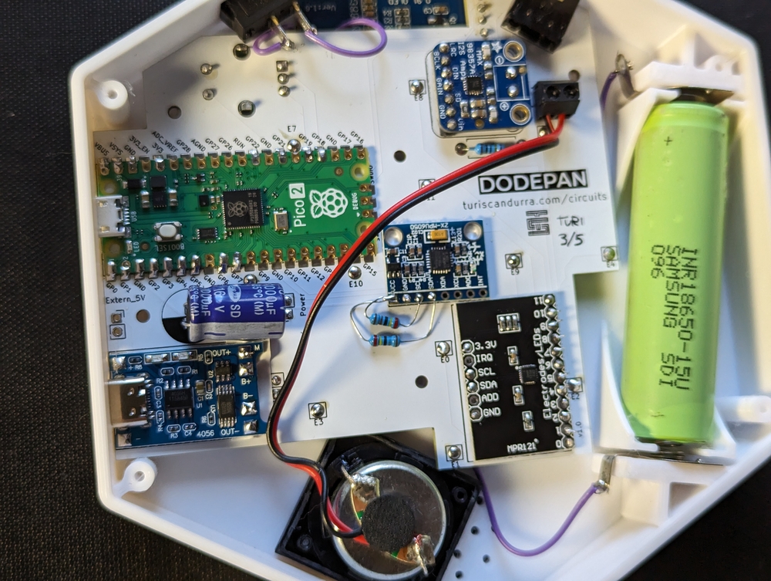
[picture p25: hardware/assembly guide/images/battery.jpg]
battery

1. Flash the firmware on the Pico
2. Install the lid and secure it with the M2 screws

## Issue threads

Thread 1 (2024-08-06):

I2S on Dodepan

grbfst, 2024-08-06:
Hi,
Love the project. How hard/easy is it to implement an I2S sound output on the Dodepan? I see you have already done it for the Picophonica so maybe it's easy (and I don't know how) ?

TuriSc, 2024-08-13:
Hi.
A new version of Dodepan is under development at [TuriSc/Dodepan-I2S](https://github.com/TuriSc/Dodepan-I2S/). It does output sound via I2S, but it's not sample-based as it uses a new audio engine for direct digital synthesis.
This older repository will only cover the PWM version of the instrument.

Closed 2024-08-13.

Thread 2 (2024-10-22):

Crackling

grbfst, 2024-10-22:
Hi, Wonderful project! Just built a Pico (1) and a Pico 2 Dodepan. I noticed quite some crackling, do I need to change something in the I2S settings?

Regards,
Marc

grbfst, 2024-10-22:
It's only when playing a note, I do need the gain because without the resistor the sound is quite soft. I tried no resistor, resistor to ground and to VDD but all give crackling.

TuriSc, 2024-10-23:
Could you please try a smaller speaker (or headphones)? If the crackling stops or is reduced, then it's a power issue, and a decoupling capacitor between the amp's VDD and GND might help.

However, it could be that your CPU is struggling to keep up with audio buffering. Does the problem go away if you disable the two IMU-controlled effects? Disabling them frees up quite some CPU cycles.

A Pico 1 would not be fast enough to flawlessly play multiple notes and process IMU effects at the same time, unless the CPU is overclocked even more, which will affect the overall tuning of the instrument.

grbfst, 2024-10-23:
I will look at the code and see if where I can disable the effects.

Closed 2024-12-01.

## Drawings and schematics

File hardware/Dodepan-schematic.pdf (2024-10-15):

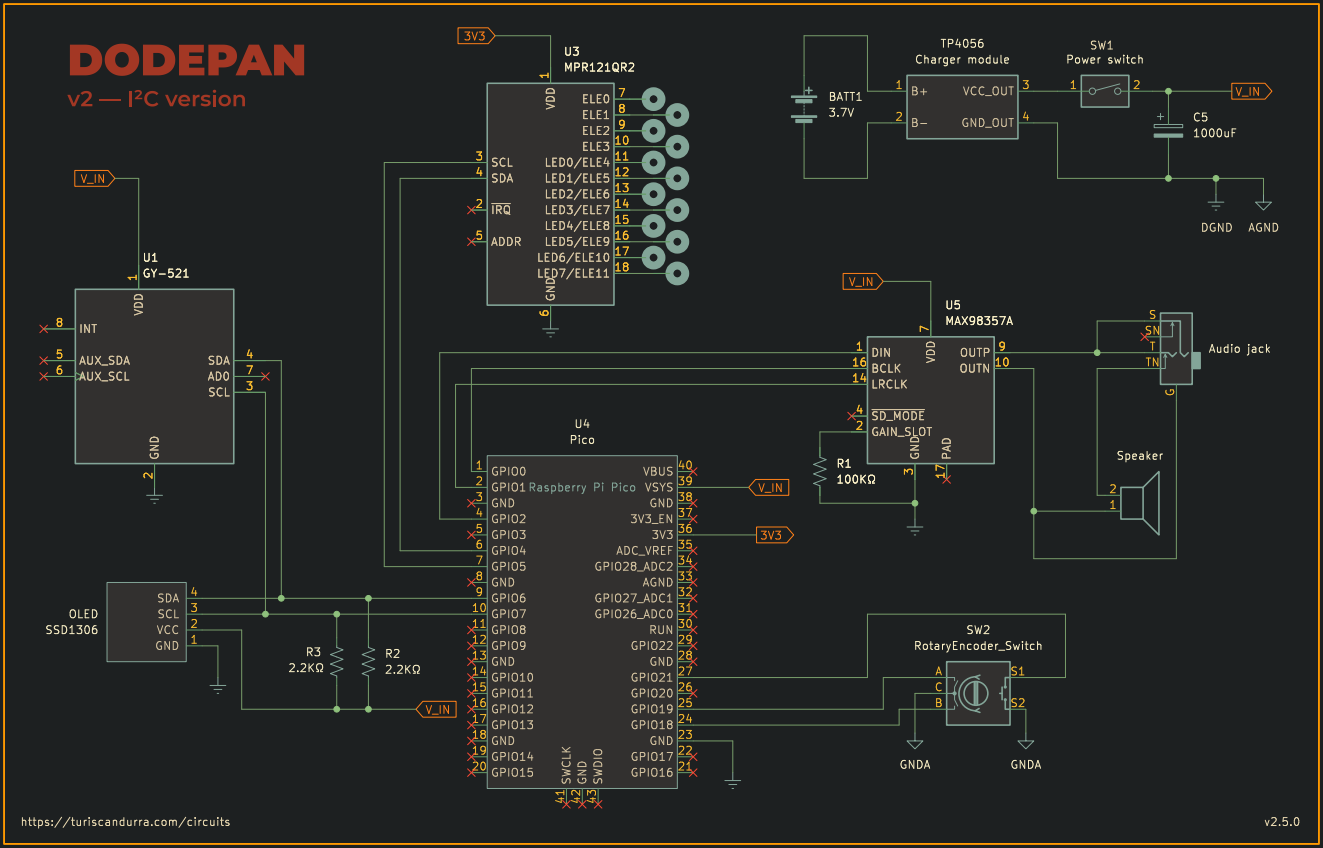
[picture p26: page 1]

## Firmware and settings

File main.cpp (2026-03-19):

/* Dodepan
 * An expressive electronic instrument and Midi controller built on Raspberry Pi Pico".
 * By Turi Scandurra – https://turiscandurra.com/circuits
 */

#include "config.h"         // Most configurable options are here
#include "pico/stdlib.h"
// Arduino types added for compatibility
typedef bool boolean;
typedef uint8_t byte;
#include "hardware/clocks.h"
#include "hardware/gpio.h"
#include "hardware/adc.h"   // Used for low battery detection
#include "hardware/flash.h"
#include "pico/binary_info.h"
#include "pico/multicore.h"
#include "sound_i2s.h"
#include "pra32-u-common.h" // https://github.com/risgk/digital-synth-pra32-u
#include "pra32-u-synth.h"  // PRA32-U version 2.3.1
#include "instrument_preset.h"
#include "encoder.h"        // https://github.com/TuriSc/RP2040-Rotary-Encoder
#include "button.h"         // https://github.com/TuriSc/RP2040-Button
#include "bsp/board_api.h"  // For TinyUSB Midi
#include "tusb.h"           // For TinyUSB Midi
#include "scales.h"
#include "battery-check.h"
#include "imu.h"
#include "touch.h"
#include "looper.h"
#include "display/display.h"
#include "state.h"

/* Globals */

PRA32_U_Synth g_synth;

state_t* state;

Imu_data imu_data;

uint8_t **user_presets;
uint8_t **user_scales;

#if defined (USE_DISPLAY)
ssd1306_t display;
#endif

static alarm_id_t power_on_alarm_id;
static alarm_id_t long_press_alarm_id;
static bool looper_button_pending;
static alarm_id_t flash_write_alarm_id;

void core1_main();

/* User Presets and flash memory */
static inline uint8_t get_argument_from_parameter(uint8_t parameter) {
    uint8_t control_number = dodepan_program_parameters[parameter];
    return g_synth.current_controller_value(control_number);
}

static inline void update_argument_from_parameter(uint8_t parameter) {
    uint8_t control_number = dodepan_program_parameters[parameter];
    uint8_t argument = g_synth.current_controller_value(control_number);
    set_argument(argument);
}

static inline void update_degree() {
    uint8_t step = get_step();
    uint8_t degree = get_degree(step);
    set_extended_scale(step, degree);
    set_scale_unsaved(true); // Used when the user modifies a scale but does not save it,
                             // and the name of the scale must be changed to "Custom"
}

void load_user_preset(uint8_t instrument) {
    uint8_t preset_num = instrument - 9; // Subtracting the 9 default presets
    for (uint32_t i = 0; i < PROGRAM_PARAMS_NUM; i++) {
        g_synth.control_change(dodepan_program_parameters[i], user_presets[preset_num][i]);
    }
}

static inline void sync_control_change() {
    uint8_t parameter = get_parameter();
    uint8_t control_number = dodepan_program_parameters[parameter];
    uint8_t argument = get_argument();
    g_synth.control_change(control_number, argument);
}

void update_instrument() {
    uint8_t instrument = get_instrument();
    switch (instrument) {
        case 0: // Load custom Dodepan preset
            for (uint32_t i = 0; i < PROGRAM_PARAMS_NUM; i++) {
                g_synth.control_change(dodepan_program_parameters[i], dodepan_preset[i]);
            }
            set_preset_slot(-1); // No slot selected
        break;
        case 9:
        case 10:
        case 11:
        case 12:
            load_user_preset(instrument);
            // Set preset_slot selection to match loaded instrument
            set_preset_slot(instrument - 9);
        break;
        default: // case 1-8: load PRA32-U presets
            g_synth.program_change(instrument - 1);
            set_preset_slot(-1); // No slot selected
        break;
    }
}

bool load_flash_data() { // Only called at startup
    // Read address is different than write address
    const uint8_t *stored_data = (const uint8_t *) (XIP_BASE + FLASH_TARGET_OFFSET);

    // Validation
    uint8_t magic[MAGIC_NUMBER_LENGTH] = MAGIC_NUMBER;
    bool invalid_data = false;
    for(uint8_t i=0; i<MAGIC_NUMBER_LENGTH; i++){
        if(stored_data[i] != magic[i]){ return false; } // Invalid data
    }
    
    if((stored_data[MAGIC_NUMBER_LENGTH + 0] > HIGHEST_KEY)          || // Validate key
       (stored_data[MAGIC_NUMBER_LENGTH + 1] > NUM_SCALES -1)        || // Validate scale
       (stored_data[MAGIC_NUMBER_LENGTH + 2] > 8 + NUM_PRESET_SLOTS) || // Validate instrument
       (stored_data[MAGIC_NUMBER_LENGTH + 3] > 0x03)                 || // Validate IMU configuration
       (stored_data[MAGIC_NUMBER_LENGTH + 4] > 8)                    || // Validate volume
       (stored_data[MAGIC_NUMBER_LENGTH + 5] > CONTRAST_AUTO)           // Validate contrast
    ) { return false; } // Invalid data

    // Data is valid and can be loaded safely
    set_key(             stored_data[MAGIC_NUMBER_LENGTH + 0]);
    uint8_t scale =      stored_data[MAGIC_NUMBER_LENGTH + 1] ;
    set_instrument(      stored_data[MAGIC_NUMBER_LENGTH + 2]);
    set_imu_axes(        stored_data[MAGIC_NUMBER_LENGTH + 3]);
    set_volume(          stored_data[MAGIC_NUMBER_LENGTH + 4]);
    set_contrast(        stored_data[MAGIC_NUMBER_LENGTH + 5]);

    // Load user presets
    uint8_t offset = MAGIC_NUMBER_LENGTH + 12;
    for (uint8_t i = 0; i < NUM_PRESET_SLOTS; i++) {
        for (uint8_t j = 0; j < PROGRAM_PARAMS_NUM; j++) {
            user_presets[i][j] = stored_data[offset++];
        }
    }
    update_instrument();

    // Load user scales
    for (uint8_t i = 0; i < NUM_SCALE_SLOTS; i++) {
        for (uint8_t j = 0; j < 12; j++) {
            user_scales[i][j] = stored_data[offset++];
        }
    }
    set_and_extend_scale(scale);

#if defined (USE_DISPLAY)
    display_update_contrast(&display);
#endif

    return true;
}

int64_t write_flash_data(alarm_id_t id, void *) {
    // Initialize the buffer with a signature
    uint8_t flash_buffer[FLASH_PAGE_SIZE] = MAGIC_NUMBER;
    uint8_t index = MAGIC_NUMBER_LENGTH;

    // Gather the rest of the data
    flash_buffer[MAGIC_NUMBER_LENGTH + 0] = get_key();
    flash_buffer[MAGIC_NUMBER_LENGTH + 1] = get_scale();
    flash_buffer[MAGIC_NUMBER_LENGTH + 2] = get_instrument();
    flash_buffer[MAGIC_NUMBER_LENGTH + 3] = get_imu_axes();
    flash_buffer[MAGIC_NUMBER_LENGTH + 4] = get_volume();
    flash_buffer[MAGIC_NUMBER_LENGTH + 5] = get_contrast();

    // Stop here if the stored data is the same as what we're about to write
    const uint8_t *stored_data = (const uint8_t *) (XIP_BASE + FLASH_TARGET_OFFSET);
    if( stored_data[MAGIC_NUMBER_LENGTH + 0] == flash_buffer[MAGIC_NUMBER_LENGTH + 0] &&
        stored_data[MAGIC_NUMBER_LENGTH + 1] == flash_buffer[MAGIC_NUMBER_LENGTH + 1] &&
        stored_data[MAGIC_NUMBER_LENGTH + 2] == flash_buffer[MAGIC_NUMBER_LENGTH + 2] &&
        stored_data[MAGIC_NUMBER_LENGTH + 3] == flash_buffer[MAGIC_NUMBER_LENGTH + 3] &&
        stored_data[MAGIC_NUMBER_LENGTH + 4] == flash_buffer[MAGIC_NUMBER_LENGTH + 4] &&
        stored_data[MAGIC_NUMBER_LENGTH + 5] == flash_buffer[MAGIC_NUMBER_LENGTH + 5] &&
        get_preset_has_changes() == false &&
        get_scale_has_changes()  == false) { return 0; }

    // Reserving bytes MAGIC_NUMBER_LENGTH + [6-11] for future firmware versions

    // Add user presets to the write buffer
    uint8_t offset = MAGIC_NUMBER_LENGTH + 12;
    for (uint8_t i = 0; i < NUM_PRESET_SLOTS; i++) {
        for (uint8_t j = 0; j < PROGRAM_PARAMS_NUM; j++) {
            flash_buffer[offset++] = user_presets[i][j];
        }
    }

    // Add user scales to the write buffer
    for (uint8_t i = 0; i < NUM_SCALE_SLOTS; i++) {
        for (uint8_t j = 0; j < 12; j++) {
            flash_buffer[offset++] = user_scales[i][j];
        }
    }

    // Turn on built-in LED
    gpio_put(PICO_DEFAULT_LED_PIN, 1);

    // Stop audio and synth processes on core1
    multicore_reset_core1();

    // Disable interrupts, write, and restore interrupts
    uint32_t ints_id = save_and_disable_interrupts();
	flash_range_erase(FLASH_TARGET_OFFSET, FLASH_SECTOR_SIZE); // Required for flash_range_program to work
	flash_range_program(FLASH_TARGET_OFFSET, flash_buffer, FLASH_PAGE_SIZE);
	restore_interrupts (ints_id);

    // Restart processes on core1
    multicore_launch_core1(core1_main);

    // Wash "dirty" flags
    set_preset_has_changes(false);
    set_scale_has_changes(false);

    // Turn off built-in LED
    gpio_put(PICO_DEFAULT_LED_PIN, 0);

    return 0;
}

void request_flash_write() {
    // Schedule writing settings to flash.
    // This delay is introduced to minimize write operations.
    if (flash_write_alarm_id) cancel_alarm(flash_write_alarm_id);
    flash_write_alarm_id = add_alarm_in_ms(FLASH_WRITE_DELAY_S * 1000, write_flash_data, NULL, true);
}

void submit_preset_slot() {
    int8_t slot = get_preset_slot();
    if(slot == -1) { return; }
    for (uint8_t i = 0; i < PROGRAM_PARAMS_NUM; i++) {
        user_presets[slot][i] = get_argument_from_parameter(i);
    }
    set_preset_has_changes(true);
    request_flash_write();

    // Since we've written a preset, let's select it on the main screen
    set_instrument(9 + slot);
}

void submit_scale_slot() {
    int8_t slot = get_scale_slot();
    if(slot == -1) { return; }
    for (uint8_t i = 0; i < 12; i++) {
        user_scales[slot][i] = get_extended_scale(i);
    }
    set_scale_has_changes(true);
    set_scale_unsaved(false); // Used when the user modifies a scale but does not save it,
                              // and the name of the scale must be changed to "Custom"

    request_flash_write();

    // Since we've written a scale, let's select it on the main screen
    set_scale(NUM_SCALES_BUILTIN + slot);
}

/* Note and audio */

uint8_t get_note_by_id(uint8_t id) {
    return get_key() + get_extended_scale(id);
}

static const struct sound_i2s_config sound_config = {
    .pio_num         = I2S_PIO_NUM,
    .pin_scl         = I2S_CLOCK_PIN_BASE,
    .pin_sda         = I2S_DATA_PIN,
    .pin_ws          = I2S_CLOCK_PIN_BASE + 1,
    .sample_rate     = SOUND_OUTPUT_FREQUENCY,
    .bits_per_sample = 16,
    .samples_per_buffer = AUDIO_BUFFER_LENGTH,
};

static inline uint32_t tudi_midi_write24 (uint8_t jack_id, uint8_t b1, uint8_t b2, uint8_t b3) {
    uint8_t msg[3] = { b1, b2, b3 };
    return tud_midi_stream_write(jack_id, msg, 3);
}

void note_on(uint8_t id, uint8_t velocity) {
    uint8_t note = get_note_by_id(id);
    g_synth.note_on(note, velocity);
    tudi_midi_write24(0, 0x90, note, velocity);
}

void note_off(uint8_t id) {
    uint8_t note = get_note_by_id(id);
    g_synth.note_off(note);
    tudi_midi_write24(0, 0x80, note, 0);
}

void touch_on(uint8_t id) {
    // Set the velocity according to accelerometer data.
    // The range of velocity is 0-127, but here it's clamped to 64-127
    uint8_t velocity = imu_data.acceleration;

    if (looper_is_playing()) {
        if (get_context() != CTX_LOOPER) {
            looper_stop(); // Stop playback, preserve recording, don't start a new one
            note_on(id, velocity);
#if defined (USE_DISPLAY)
            display_draw(&display);
#endif
            return;
        }
        all_notes_off(); // Stop loop notes before playing the new note
    }
    note_on(id, velocity);
    if (get_context() == CTX_LOOPER) {
        looper_record(id, velocity, true);
    }

    // Since a note_on event can start the looper recording,
    // a display draw needs to be called here.
#if defined (USE_DISPLAY)
    display_draw(&display);
#endif
}

void touch_off(uint8_t id) {
    note_off(id);
    if (get_context() == CTX_LOOPER) {
        looper_record(id, 0, false);
    }
}

void all_notes_off() {
    g_synth.all_notes_off();
}

// Use the IMU to alter parameters according to device tilting
void tilt_process() {
    if(get_imu_axes() & 0x02) {
        g_synth.control_change(FILTER_CUTOFF, imu_data.deviation_y);
    }

    // Split the bytes
    uint8_t bending_lsb = imu_data.deviation_x & 0x7F;
    uint8_t bending_msb = (imu_data.deviation_x >> 7) & 0x7F;

    // Send the instruction to the synth
    if(get_imu_axes() & 0x01) {
        g_synth.pitch_bend(bending_lsb, bending_msb);

#if defined (USE_MIDI)
        static uint8_t throttle;
        if(throttle++ % 10 != 0) return; // Limit the message rate
        // Pitch wheel range is between 0 and 16383 (0x0000 to 0x3FFF),
        // with 8192 (0x2000) being the center value.
        // Send the Midi message
        tudi_midi_write24 (0, 0xE0, bending_lsb, bending_msb);
#endif
    }
}

static void __not_in_flash_func(i2s_audio_task)(void) {
    static int16_t *last_buffer;
    int16_t *buffer = sound_i2s_get_next_buffer();
    int16_t right_buffer; // Necessary quirk for compatibility with
                          // the original PRA32-U code
            
    if (buffer != last_buffer) { 
        last_buffer = buffer;
        for (int i = 0; i < AUDIO_BUFFER_LENGTH; i++) {
        short sample = g_synth.process(0, right_buffer);
        int temp = (int)sample * get_volume();
        short output = (short)(temp >> 3);
        *buffer++ = output;
        *buffer++ = output;
        }
    }
}

int64_t power_on_complete(alarm_id_t id, void *) {
    gpio_put(PICO_DEFAULT_LED_PIN, 0);
    return 0;
}

void intro_complete() {
    set_context(CTX_SELECTION);
}

/* I/O functions */

void encoder_up() {
    context_t context = get_context();
    switch (context) {
        case CTX_SELECTION:
            set_selection_up();
            // Force a display refresh, to clear out any glitches that might
            // have occurred earlier due to I²C timeouts
#if defined (USE_DISPLAY)
            switch(get_selection()) {
                case SELECTION_KEY:
                case SELECTION_LOOPER:
                case SELECTION_IMU_CONFIG:
                    display_refresh(&display);
                break;
            }
#endif
        break;
        case CTX_KEY:
            // D#7 is the highest note that can be set as root note
            set_key_up();
            all_notes_off();
        break;
        case CTX_SCALE:
            set_scale_up();
            all_notes_off();
        break;
        case CTX_INSTRUMENT:
            set_instrument_up();
            update_instrument();
        break;
        case CTX_IMU_CONFIG:
            set_imu_axes_up();
        break;
        case CTX_VOLUME:
            set_volume_up();
        break;
        case CTX_CONTRAST:
            set_contrast_up();
#if defined (USE_DISPLAY)
            display_update_contrast(&display);
#endif
        break;
        case CTX_SYNTH_EDIT_PARAM:
            set_parameter_up();
            update_argument_from_parameter(get_parameter());
        break;
        case CTX_SYNTH_EDIT_ARG:
            set_argument_up();
            sync_control_change();
        break;
        case CTX_SYNTH_EDIT_STORE:
            set_preset_slot_up();
        break;
        case CTX_LOOPER:
            looper_transpose_up();
        break;
        case CTX_SCALE_EDIT_STEP:
            set_step_up();
        break;
        case CTX_SCALE_EDIT_DEG:
            set_degree_up();
            update_degree();
        break;
        case CTX_SCALE_EDIT_STORE:
            set_scale_slot_up();
        break;
        case CTX_INIT:
        case CTX_INFO:
        default:
            ; // Do nothing
        break;
    }
#if defined (USE_DISPLAY)
    if(get_contrast() == CONTRAST_AUTO) {
        display_wake(&display);
    }
    display_draw(&display);
#endif
}

void encoder_down() {
    context_t context = get_context();
    switch (get_context()) {
        case CTX_SELECTION:
            set_selection_down();
            // Force a display refresh, to clear out any glitches that might
            // have occurred earlier due to I²C timeouts
#if defined (USE_DISPLAY)
            switch(get_selection()) {
                case SELECTION_VOLUME:
                case SELECTION_LOOPER:
                case SELECTION_IMU_CONFIG:
                    display_refresh(&display);
                break;
            }
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
int main() {
    // Adjust the clock speed to be an even multiplier
    // of the audio sampling frequency
    if (SOUND_OUTPUT_FREQUENCY % 11025 == 0) { // For 22.05, 44.1, 88.2 kHz
        set_sys_clock_khz(135600, false);
    } else if (SOUND_OUTPUT_FREQUENCY % 8000 == 0) { // For 8, 16, 32, 48, 96, 192 kHz
        set_sys_clock_khz(147600, false);
    }
    stdio_init_all();

    bi_decl_all();

#if defined (USE_MIDI)
    // Enable Midi device functionality
    board_init();
    tud_init(BOARD_TUD_RHPORT);

    if (board_init_after_tusb) {
        board_init_after_tusb();
    }
#endif

    // Initialize display and IMU (sharing an I²C bus)
#if defined (USE_DISPLAY) || defined (USE_IMU)
    gpio_init(SSD1306_SDA_PIN);
    gpio_init(SSD1306_SCL_PIN);
    gpio_set_function(SSD1306_SDA_PIN, GPIO_FUNC_I2C);
    gpio_set_function(SSD1306_SCL_PIN, GPIO_FUNC_I2C);
    // External pullup resistors are required (2.2KΩ to 4.7KΩ recommended)
    // gpio_pull_up(SSD1306_SDA_PIN);
    // gpio_pull_up(SSD1306_SCL_PIN);

    i2c_init(SSD1306_I2C_PORT, SSD1306_I2C_FREQ);
#endif

#if defined (USE_DISPLAY)
    display_init(&display);
#endif

#if defined (USE_IMU)
    imu_init(); // MPU6050
#endif

    // Start the audio engine.
    sound_i2s_init(&sound_config);

    // Start the synth
    g_synth.initialize();

    // Initialize the state
    state = get_state();
    set_context(CTX_INIT);
    set_low_batt(false);
    set_preset_slot(-1); // No slot selected
    set_scale_slot(-1);  // No slot selected
    set_preset_has_changes(false);
    set_scale_has_changes(false);

    // Allocate memory for the user presets and scales arrays
    user_presets = (uint8_t **)malloc(NUM_PRESET_SLOTS * sizeof(uint8_t *));
    for (uint8_t i = 0; i < NUM_PRESET_SLOTS; i++) {
        user_presets[i] = (uint8_t *)malloc(PROGRAM_PARAMS_NUM * sizeof(uint8_t));
    }

    user_scales = (uint8_t **)malloc(NUM_SCALE_SLOTS * sizeof(uint8_t *));
    for (uint8_t i = 0; i < NUM_SCALE_SLOTS; i++) {
        user_scales[i] = (uint8_t *)malloc(12 * sizeof(uint8_t));
    }

    // Attempt to load previous settings, if stored on flash
    bool data_loaded = load_flash_data();
    if(!data_loaded) {
        // Settings not loaded, initialize state with default values
        set_key(60); // C4
        set_and_extend_scale(0); // Major
        set_scale_unsaved(false);
        set_instrument(0); // Dodepan custom preset
        update_instrument();
        set_imu_axes(0x02); // Filter cutoff modulation enabled, pitch bending disabled
        set_volume(8); // Max value
        set_contrast(CONTRAST_AUTO); // Automatic dimming of display brightness
#if defined (USE_DISPLAY)
        display_update_contrast(&display);
#endif
        // Copy the custom preset to the four user preset slots
        for (uint8_t i = 0; i < NUM_PRESET_SLOTS; i++) {
            for (uint8_t j = 0; j < PROGRAM_PARAMS_NUM; j++) {
                user_presets[i][j] = dodepan_preset[j];
            }
        }
        // Set all user scales to chromatic
        for (uint8_t i = 0; i < NUM_SCALE_SLOTS; i++) {
            for (uint8_t j = 0; j < 12; j++) {
                user_scales[i][j] = j;
            }
        }
    }

    // Launch the routine on the second core
    multicore_launch_core1(core1_main);

    // Initialize the touch module
    mpr121_i2c_init();

    // Initialize the looper with a maximum of 512 note events
    looper_init(512);

    // Initialize the rotary encoder and switch
    button_system_init();
    encoder_system_init();
#if defined (ENCODER_USE_PULLUPS)
    gpio_pull_up(ENCODER_DT_PIN);
    gpio_pull_up(ENCODER_CLK_PIN);
    gpio_pull_up(ENCODER_SWITCH_PIN);
#endif
    rotary_encoder_t *encoder = create_encoder(ENCODER_DT_PIN, ENCODER_CLK_PIN, encoder_onchange);
    button_t *button = create_button(ENCODER_SWITCH_PIN, button_onchange);

    // Falloff values in case the IMU is disabled
    imu_data.deviation_x = 0x2000;  // Center value
    imu_data.deviation_y = 64;      // Center value
    imu_data.acceleration = 127;    // Max value

    // Use the onboard LED as a power-on indicator
    gpio_init(PICO_DEFAULT_LED_PIN);
    gpio_set_dir(PICO_DEFAULT_LED_PIN, GPIO_OUT);
    gpio_put(PICO_DEFAULT_LED_PIN, 1);
    power_on_alarm_id = add_alarm_in_ms(500, power_on_complete, NULL, true);

    // Initialize the ADC, used for voltage sensing
    adc_init();
    // Launch the battery check timed task
    battery_check_init(5000, NULL, (void*)battery_low_detected);

#if defined (USE_DISPLAY)
    // Show a short intro animation. This will distract the user
    // while the hardware is calibrating
    intro_animation(&display, intro_complete);
    display_draw(&display);
#else
    // Since there's no intro animation without a display,
    // let's trigger the new state manually
    set_context(CTX_SELECTION);
#endif

    while (true) { // Main loop
        encoder_poll_all_events();
        mpr121_task();

#if defined (USE_IMU)
        if(get_imu_axes() > 0) {
            imu_task(&imu_data);
            tilt_process();
        }
#endif
        looper_task();
#if defined (USE_MIDI)
        tud_task(); // tinyusb device task
#endif
    }
}

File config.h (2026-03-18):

#ifndef CONFIG_H_
#define CONFIG_H_

/* Device identifiers */
#define PROGRAM_NAME                "Dodepan"
#define PROGRAM_VERSION             "2.5.2"
#define PROGRAM_DESCRIPTION         "Portable musical instrument and MIDI controller"
#define PROGRAM_URL                 "https://turiscandurra.com/circuits"
#define USB_STR_MANUFACTURER        "TuriScandurra"
#define USB_STR_PRODUCT             "Dodepan"

/* I/O */
#define BATT_LVL_PIN                29
#define BATT_LVL_DESCRIPTION        "Battery sensing pin"

#define ENCODER_USE_PULLUPS         true // Set to true if using a bare rotary encoder like EC11.
                                         // Set to false if you have a breakout board with external pullup resistors.
#define ENCODER_DT_PIN              18
#define ENCODER_DT_DESCRIPTION      "Encoder data pin"
#define ENCODER_CLK_PIN             19
#define ENCODER_CLK_DESCRIPTION     "Encoder clock pin"
#define ENCODER_SWITCH_PIN          21
#define ENCODER_SWITCH_DESCRIPTION  "Encoder switch"
#define LONG_PRESS_THRESHOLD        1000 // Amount of ms to hold the button to trigger a long press

/* SSD1306 Display */
#define USE_DISPLAY
#define SSD1306_I2C_PORT            i2c1
#define SSD1306_SDA_PIN             6 // i2c1
#define SSD1306_SDA_DESCRIPTION     "SSD1306 SDA"
#define SSD1306_SCL_PIN             7 // i2c1
#define SSD1306_SCL_DESCRIPTION     "SSD1306 SCL" // Labeled SCL or SCK
#define SSD1306_ADDRESS             0x3C
#define SSD1306_WIDTH               128
#define SSD1306_HEIGHT              32
#define SSD1306_I2C_FREQ            400 * 1000 // 400kHz
// #define SSD1306_ROTATE           // Rotate the display by 180°
#define DISPLAY_DIM_DELAY           5   // Seconds since last UI interaction for the screen
                                        // to be dimmed when constrast is set to AUTO

/* GY-521 - MPU6050 accelerometer and gyroscope */
// Note: the display and the MPU share the same I²C bus and pins
#define USE_IMU                     // The IMU is optional, but gives you velocity and bending
#define MPU6050_I2C_PORT            i2c1
#define MPU6050_SDA_PIN             SSD1306_SDA_PIN
#define MPU6050_SDA_DESCRIPTION     "MPU6050 SDA"
#define MPU6050_SCL_PIN             SSD1306_SCL_PIN
#define MPU6050_SCL_DESCRIPTION     "MPU6050 SCL"

#define MPU6050_ADDRESS             0x68
#define MPU6050_SWAP_X_Y            true // Setting all three to true because of the module
#define MPU6050_FLIP_X              true // orientation when mounted inside the enclosure
#define MPU6050_FLIP_Y              true

#define PLUS " + "
#define SSD1306_MPU6050_SDA_DESCRIPTION SSD1306_SDA_DESCRIPTION PLUS MPU6050_SDA_DESCRIPTION
#define SSD1306_MPU6050_SCL_DESCRIPTION SSD1306_SCL_DESCRIPTION PLUS MPU6050_SCL_DESCRIPTION

/* MPR121 */
#define MPR121_I2C_PORT             i2c0
#define MPR121_SDA_PIN              4 // i2c0
#define MPR121_SDA_DESCRIPTION      "MPR121 SDA"
#define MPR121_SCL_PIN              5 // i2c0
#define MPR121_SCL_DESCRIPTION      "MPR121 SCL"

#define MPR121_ADDRESS              0x5A
#define MPR121_I2C_FREQ             400 * 1000 // 100kHz

#define MPR121_TOUCH_THRESHOLD      32 // These values might have to be adjusted based on the
#define MPR121_RELEASE_THRESHOLD    64 // size of your electrodes and their distance from the chip.
                                       // Threshold range is 0-255. If set incorrectly, you will get
                                       // "ghost" note_on and note_off events.
#define MPR121_DEBOUNCE_THRESHOLD   46 // Larger values allow holding the electrode for longer without
                                       // triggering a new note_on event, but make it harder for the
                                       // sensor to detect quick subsequent taps

#define VELOCITY_HOLD_SAMPLES       127 // How long to hold the peak value from accelerometer data.
#define VELOCITY_MULTIPLIER         4   // Higher values yield higher velocity, but
                                        // lower the dynamic range.

/* Audio and synth */
#define PRA32_U_MIDI_CH             0  // 0-based
#define g_midi_ch                   PRA32_U_MIDI_CH // Required for compatibility with PRA32-U library

#define AUDIO_BUFFER_LENGTH         64
#define SOUND_OUTPUT_FREQUENCY      48000
#define PICO_AUDIO_I2S_MONO_OUTPUT

#define I2S_PIO_NUM                 0 // 0 for pio0, 1 for pio1
#define I2S_DATA_PIN                2 // -> I2S DIN
#define I2S_DATA_DESCRIPTION        "I2S DIN"
#define I2S_CLOCK_PIN_BASE          0 // -> I2S BCK
#define I2S_BCK_DESCRIPTION         "I2S BCK"
#define I2S_LRCK_DESCRIPTION        "I2S LRCK" // Must be BCK+1
// The third required connection is GPIO 1 -> I2S LRCK (BCK+1)

#define LPF_MIN                     64 // Lowest filter cutoff frequency on a 0-127 scale.
#define HIGHEST_KEY                 99 // Highest note that can be set as root note

#define USE_MIDI                    // Remove this line to disable Midi output
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

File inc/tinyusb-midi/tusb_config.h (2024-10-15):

/*
 * The MIT License (MIT)
 *
 * Copyright (c) 2019 Ha Thach (tinyusb.org)
 *
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
 */

#ifndef _TUSB_CONFIG_H_
#define _TUSB_CONFIG_H_

#ifdef __cplusplus
 extern "C" {
#endif

// RHPort number used for device can be defined by board.mk, default to port 0
#ifndef BOARD_TUD_RHPORT
#define BOARD_TUD_RHPORT      0
#endif

// RHPort max operational speed can defined by board.mk
#ifndef BOARD_TUD_MAX_SPEED
#define BOARD_TUD_MAX_SPEED   OPT_MODE_DEFAULT_SPEED
#endif

//--------------------------------------------------------------------
// COMMON CONFIGURATION
//--------------------------------------------------------------------

// defined by board.mk
#ifndef CFG_TUSB_MCU
  #error CFG_TUSB_MCU must be defined
#endif

#ifndef CFG_TUSB_OS
#define CFG_TUSB_OS                 OPT_OS_PICO
#endif

// CFG_TUSB_DEBUG is defined by compiler in DEBUG build
// #ifndef CFG_TUSB_DEBUG
// #define CFG_TUSB_DEBUG        0
// #endif

// Enable Device stack
#define CFG_TUD_ENABLED       1

// Default is max speed that hardware controller could support with on-chip PHY
#define CFG_TUD_MAX_SPEED     BOARD_TUD_MAX_SPEED

/* USB DMA on some MCUs can only access a specific SRAM region with restriction on alignment.
 * Tinyusb use follows macros to declare transferring memory so that they can be put
 * into those specific section.
 * e.g
 * - CFG_TUSB_MEM SECTION : __attribute__ (( section(".usb_ram") ))
 * - CFG_TUSB_MEM_ALIGN   : __attribute__ ((aligned(4)))
 */
#ifndef CFG_TUSB_MEM_SECTION
#define CFG_TUSB_MEM_SECTION
#endif

#ifndef CFG_TUSB_MEM_ALIGN
#define CFG_TUSB_MEM_ALIGN          __attribute__ ((aligned(4)))
#endif

//--------------------------------------------------------------------
// DEVICE CONFIGURATION
//--------------------------------------------------------------------

#ifndef CFG_TUD_ENDPOINT0_SIZE
#define CFG_TUD_ENDPOINT0_SIZE    64
#endif

//------------- CLASS -------------//
#define CFG_TUD_CDC               0
#define CFG_TUD_MSC               0
#define CFG_TUD_HID               0
#define CFG_TUD_MIDI              1
#define CFG_TUD_VENDOR            0

// MIDI FIFO size of TX and RX
#define CFG_TUD_MIDI_RX_BUFSIZE   (TUD_OPT_HIGH_SPEED ? 512 : 64)
#define CFG_TUD_MIDI_TX_BUFSIZE   (TUD_OPT_HIGH_SPEED ? 512 : 64)

#ifdef __cplusplus
 }
#endif

#endif /* _TUSB_CONFIG_H_ */

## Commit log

2023-03-31 Updated pin definitions for PCB version
2023-10-28 Updated include path for bsp/board_api.h
2023-10-28 Updated submodules button, moving_average and pwm_dma_audio to the latest version
2024-05-28 Replaced buttons with rotary encoder
    [config.h]
2024-05-29 Replaced sample-based audio engine with direct synthesis
    [config.h, touch.c]
2024-05-31 Reconnected IMU code. Replaced 'Detuning' with 'Bending'
    [config.h, imu.c]
2024-05-31 Rewritten IMU data parsing routines; Removed RingBufMax
2024-05-31 Repositioned encoder pins
2024-06-11 Added pico-ssd1306 library
2024-06-11 Now showing encoder and key state on display
2024-06-17 Removed Pico Extras dependency
2024-06-21 Better preset; IMU now controls pitch bending and filter cutoff
2024-06-21 Removed on-device instrument editing
2024-06-21 Added onboard IMU destination configuration; Long press to enter IMU config; Icons
2024-06-21 Added low battery icon
2024-06-22 Removed LED blinking
2024-06-22 Clear an outline around the low battery icon to avoid overlaps
    [main.cpp]
2024-06-23 Completed tests without IMU and display
2024-06-25 Streamlined IMU calculations
2024-06-27 Fixed an incorrect velocity calculation
    [imu.c, main.cpp]
2024-06-28 Greatly streamlined IMU calculations
2024-06-30 Added option to use external pullups with the rotary encoder
2024-07-04 Redesigned the menu system, added info screen and instrument editing
    [main.cpp]
2024-07-07 Renamed Gyro to IMU on config.h and icon names
2024-07-14 Added renamed IMU icon headers
2024-07-14 Switched pico-ssd1306 library to forked version to support display rotation
2024-07-14 Swapped encoder data and clock pins
    [config.h]
2024-07-14 Added axes flip config options
    [config.h, imu.c]
2024-08-15 Force note off events when playback is interrupted
2024-08-18 Only send pitch bending Midi message if the corresponding axis is enabled
2024-08-19 Only process imu on main loop if either axis is enabled
2024-08-20 Clearer IMU routine
2024-08-22 Filter cutoff modulation enabled, pitch bending disabled by default
2024-08-22 Replace menu title with long press on instrument name for edit mode
    [main.cpp]
2024-08-23 Implement peak-hold of accelerometer data for cleaner velocity detection
2024-09-07 Change encoder pins to match PCB connections
2024-09-08 Fix syntax error when USE_MIDI is not defined
    [main.cpp]
2024-09-20 Add note about external pullup resistors on RP2350
2024-09-20 Add note about non-FPU math on imu.c
2024-09-20 Edit note about recommended range of pullup resistor value
2024-09-20 Bump version number to align firmware, PCB, and enclosure versions for first release
2024-09-23 Add on-device display contrast control
2024-09-23 Add schematic
2024-10-15 Add PCB files, assembly guide, and enclosure files
    [Dodepan_PCB_THT.kicad_pro-B_Cu.gbr, Dodepan_PCB_THT.kicad_pro-B_Mask.gbr, Dodepan_PCB_THT.kicad_pro-B_Paste.gbr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]
2024-12-27 Add forced display refresh to clear out I2C timeout glitches
    [config.h, main.cpp]
2024-12-28 Correct position of jack socket opening on the enclosure
    [Enclosure_PCB.scad, Enclosure_PCB.stl]
2024-12-29 Remove outdated version label; Fix incorrect comment about set_contrast()
    [main.cpp]
2026-03-17 Fix image links in assembly guide
2026-03-17 Embed logo into Lid.scad
    [Lid.scad, logo.dxf]
2026-03-18 Update submodules, add rotary encoder and button polling
